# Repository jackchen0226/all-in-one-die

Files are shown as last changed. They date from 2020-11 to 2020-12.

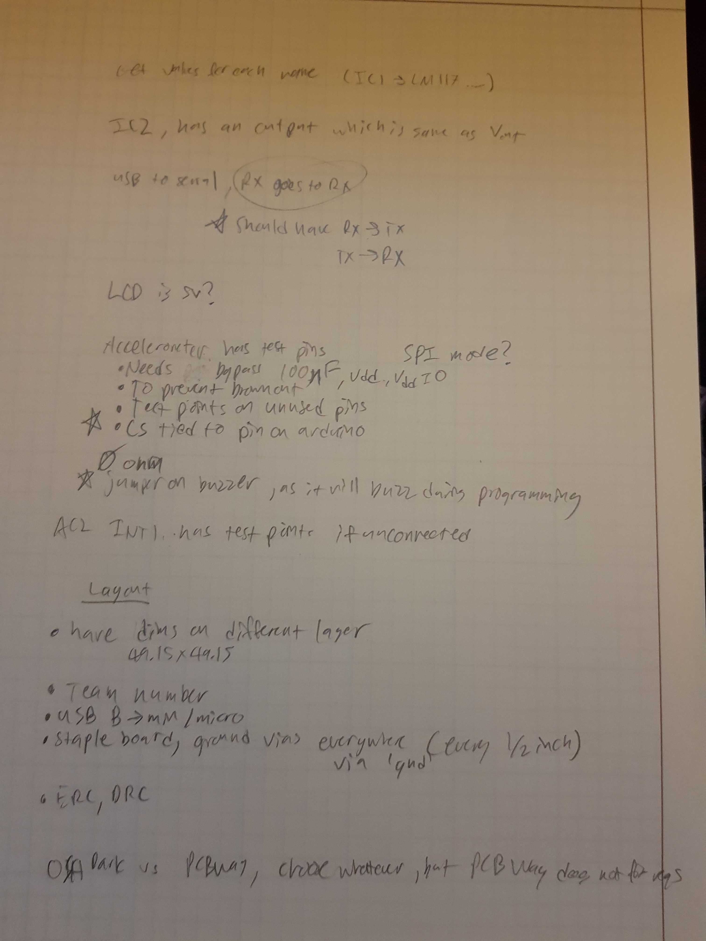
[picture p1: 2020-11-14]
docs/Design Reviews/2020-11-14/20201114_132937.jpg

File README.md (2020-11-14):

<p align="center">
  Team 7
</p>

<h3 align="center">ECE 411 Practicum Project</h3>

<p align="center">
  Practicum Project for Team 3 (Fall 2020)
  <br>
  <a href="https://github.com/jackchen0226/all-in-one-die/wiki"><strong>Team Wiki »</strong></a>
  <br>
  <br>
</p>

## Table of contents

- [Status](#status)
- [Overview](#overview)
- [Documentation](#documentation)
- [Creators](#creators)

## Status

All aspects are currently being developed, reviewed, and tested.

## Overview

All-in-One-Die is an extra-large die that you can shake with your own two hands! Large enough to be larger than your average d6 or d20, and it ‘rolls’ when you shake it. Additionally, when a 1 is rolled, an extremely negative sound will be played. This is for those who enjoy tabletop gaming and want a fun novelty item that is interactive.

Not family-friendly may involve swearing

## Documentation

Will be included upon completion.

## Creators

Hannah Mortimer (hmort2@pdx.edu) <br />
Devon Mickels (dmickels@pdx.edu) <br />
Nicole Fellows  (nicol27@pdx.edu) <br />
Jack Chen (chenjac@pdx.edu)

## 3 Brainstormed Ideas:

All-in-one-die  <br />
Farmbot <br />
Replacement Piano Key <br />

Please look at the [project ideas](https://github.com/jackchen0226/all-in-one-die/wiki/Project-Ideas) for full descriptions of all 3 ideas!

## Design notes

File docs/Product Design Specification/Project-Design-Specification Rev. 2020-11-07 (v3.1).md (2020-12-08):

Current Revision: 2020-11-07 (v3.1)

## Executive Summary / Concept of Operations

All-in-One-Die is an extra-large die that you can shake with your own two hands! Large enough to be bigger than your average d6 or d20, and it ‘rolls’ when you shake it. When a 1 is rolled, an extremely negative sound* will be played. Perfect for those who enjoy tabletop gaming and want a fun interactive novelty item. 

\*Not family friendly, may involve swearing

## Brief Market Analysis

The need for varying value dice is frequently felt by the tabletop gaming community. Games such as _Dungeons and Dragons_ and _Magic the Gathering_ require the use of dice for tracking the number of creatures a player can create, damage caused, and other game effects. In an average game of this type, a player can expect to have at least one set of gaming dice. A typical set will have 1 of each of the following: d4, d6, d8, d10, d12, d20, with each value ‘n’ after ‘d’ representing the possible rolls from 1 to n. Instead of having to carry around a bunch of dice, the All-in-One-Die will provide the customer with a handheld device capable of rolling each type of die.

Looking at what is available in the market for tabletop gaming, no handheld devices that match this design's functionality currently exist. There are some simple boards capable of displaying a roll on LEDs but those don’t have a practical application for gaming. The biggest competition comes from dice rolling apps and websites. While these offer a quick solution to being able to roll dice of different values, it lacks the hands on feel many gamers enjoy. Arguably, there are digital versions of games, but the type of customers this device is for want something they can physically play with. A big selling point of the device is the novelty of it and having a tangible accessory to improve the gaming experience.

Going over early projections of the cost of production, it would cost about $232.00 to manufacture 100 boards, equating to about $2.00 a board, added components and batteries brings the total up to about $20.00 per board. Using this production cost, and considering the limited batch being made, the device would be sold for about $40.00-$50.00. This cost could be brought down if it were being mass produced.

## Requirements
This project MUST:
* Have some input to change the size of the die
* Be fully enclosed in a case with the exception of inputs
* Have an on/off switch
* Have an audio device to play a sound effect upon rolling a 1
* Have a way to detect shaking of the die
* Have a screen that displays the result of the roll.
* Be portable and battery-powered with replaceable batteries
* Battery power lasts at least 1 hour
* Contain a processor
* Be live documented on Github Wiki

This project SHOULD:
* Have rechargeable batteries 
* Be created on a PCB that is as small as possible
* Contain mostly hand solder surface mount components on the board
* Have documentation and issues tracked on Github

## System Architecture
### High-Level Diagram

High level diagram, because block diagrams are important

### Low-level diagram

Low level diagram, just y'know ignore the low resolution.

## Design Specification
* Processor: ATMega328P
* Actuator: LCD Screen and Speaker
* Sensor: Accelerometer (LIS3L02AQ3)
* USB to Serial: FT232RL
* Power: 3.3V-5V
* Using Arduino IDE

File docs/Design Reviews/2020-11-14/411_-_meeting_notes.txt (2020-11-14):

team 3 

overview:
project is for tabletop gaming and the device is houses a screen and a dial on side to select
the type of die you want to roll so you can go 4 8 12 20, shake it, and it displays and and you have option to roll again or select diff

block diagram:
sensor: - lis3dh accelorometer set right now to high sensitivity, someone could set off false rolls, and a potentiometer for the button
	we didn't want to use buttons on the device, all functionality is broken into the potentiometer and the timing
Andy: i like that - thought to the UX

actuator: - with the sensor reading botht the shake and pot setting, it displays onto an oled screen - 128*32 screen, you can include messages (andy asked about messages) andrew - put skull and cross bones on it, hahahah
oled is output - other output is the buzzer for a nat 1, sound,
the controller atmega32
power supply - batteries - 4 AAs (6 volts into 5 volts)

Mini Design Review:
Devon sharing screen: the schematic overview - 
looking at power first - 2 parts, the dc female to take in power with 5v regulator, power led to show that we are getting proper power, added 3.3v for the accelormeter to conver down
	and: good job on the 5v - burn less power
		few things: what is ic1 - no value associated with it - voltage regulator we pulled off of mouser 7805? use value command so it's not just a black box - no black boxes
				lm1117 - it's got a vout, input, adj/gnd and output - the datasheet uses 4 pins but table only shows the 3 pins, 3.3v output - the tab on the transistor - vout
			we will plug batteries into that - putting the diode in there is good
			usb to serial: it's adorable - stick with low power module, miniusb port, good job on shield for capacitor to gnd, rx goes to rx - yup that's wrong, on a UART rx goes to tx, and tx goes to rx, know it and connect appropraitely
			crystal resonator is fine - good job on the bypass caps
			icsp - we gett to program it, arduino ecosystem, reset goes to left to reset the dtr thing - the lcd goes to some pins and that's 5v as well, the lcd 5v in/out? not super verified, but we have been using 5v
			Accelerometer: have a jumper that is being used as test point, incase we need to use an external, this could be a pain cause small
			WE NEED BYPASS CAPS 100nF whereever there is vdd (at least 2), any single chip that is off in space need local charge resovoirs
			using spie mode- great
			not sure we want to ground chip-select, in spie mode it needs to go to output for the chip select, cs tied to pin on arduino - we need taht, spie requires cs to go from high to low to start process
			strongly suggest test points on unused pins on microcontrollera nd accelerometer
			driving buzzer directly which is probably okay - we proabbly need to have a jumper in our buzzer so we can disconnect it when we are programming it - 0 ohm resistor or something so we can program without the buzzer in place
			run erc - interuupt pins can go to test points - or not, up to us - and then we have std power warnings that we can approve
			excellent - good schematic

		layout: all fired
			gnd plane on both sides - good
			change dimensions to different layer - they are currently copper 
			power is thick - nice
			team number needed ece411-tx-xxx (follow instructions completely)
			current goal is make board
			where is usb connector? - we have type b connector oop - it'll work, just giant
			really really good
			clean up team name layer 
			dis -tval
			more to clean up but fine
			last thing need to do - staple your board, add gnd vias every 1/2 in or so, us via cmd, via 'gnd' - put those everywhere so ground works well - in places where gnd signal cut in pieces - more the merrier
			drc - air wires and stuff to fix, make sure all are clear and we are good.

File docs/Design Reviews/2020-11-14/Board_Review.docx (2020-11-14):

Board Review with Andrew Greenberg

Power:

- Liked the linear regulator, will burn less power.
- What is IC1 running to on the power supply? Use a value set pin.
- Don’t connect Vout on the 3.3V linear regulator

USB -> Serial:

- Caps to ground look good.
- RX shouldn’t connect to RX, TX shouldn’t connect to TX, know which is input/output.

OLED:

- Double check voltage being used for screen.

Buzzer:

- Put 0 ohm resistor on buzzer so it doesn’t mess up programming.

Accelerometer:

- Can use pin 10,10 as test points

Board:

- Change dimensions to different layer, it’s currently only on one and OSH park won’t like it
- Clean up team name on board.
- USB is kind of large
- Staple board
  - Ground vias every ½ inch, the more the better
- Board dimension is actual 4 square inches

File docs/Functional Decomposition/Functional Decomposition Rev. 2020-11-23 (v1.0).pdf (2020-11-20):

System Design: Functional Decomposition

Team 03 – Jack Chen, Devon Mickels, Hannah Mortimer, Nicole Fellows

High Level Block Diagram

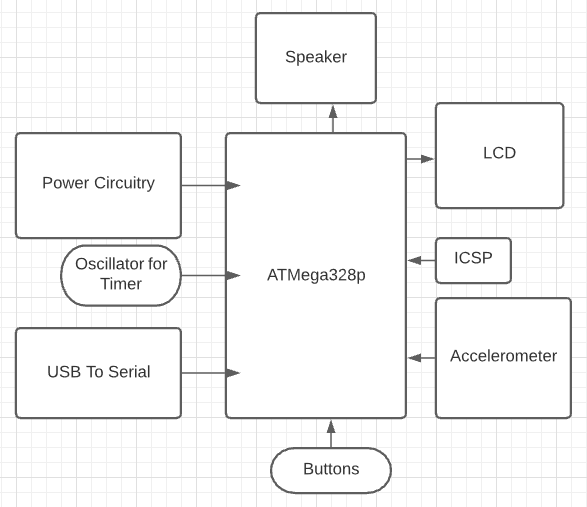
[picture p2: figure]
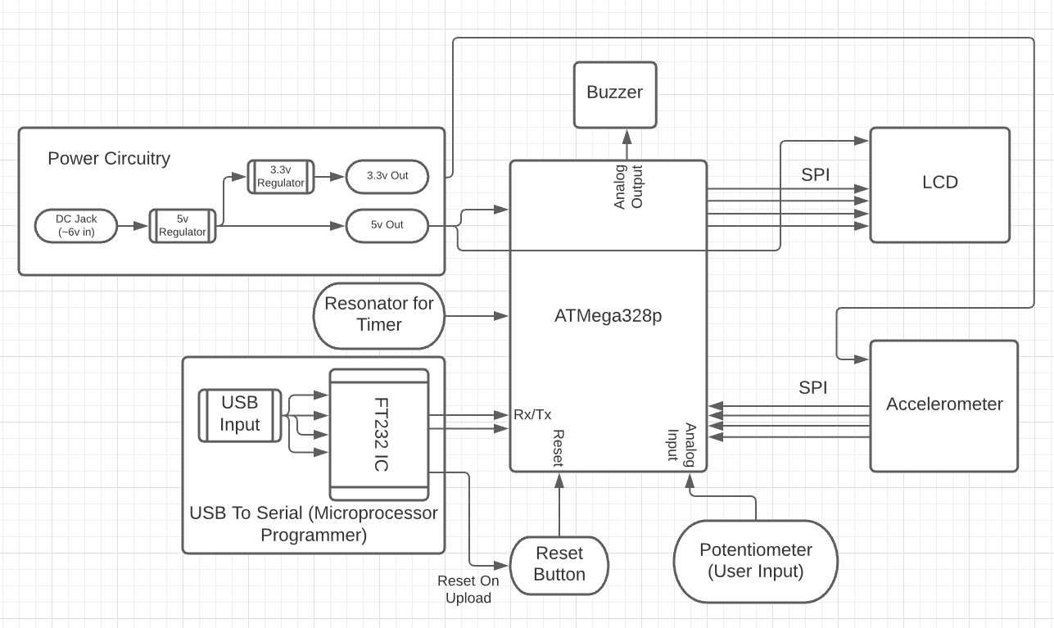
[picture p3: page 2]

Low Level Block Diagram

Power Circuitry

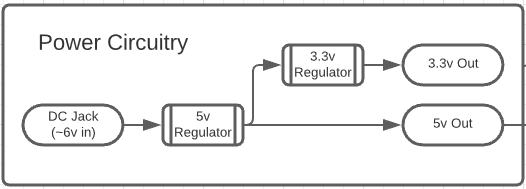
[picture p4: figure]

Module | Power Circuitry
Inputs | 6V
Outputs | 5V and 3.3V
Functionality | Converts 6v power from battery pack into a 5v and 3.3v line to power different components in the system.

USB To Serial

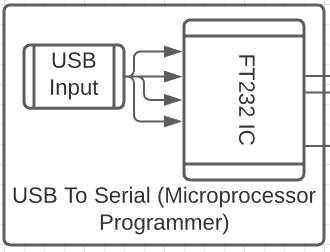
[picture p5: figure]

Module | Power Circuitry
Inputs | USB B Cable
Outputs | TX, RX and DTR signal.
Functionality | Used to convert an incoming USB signal to a usable serial communication protocol for use in programming the ATMEGA328p

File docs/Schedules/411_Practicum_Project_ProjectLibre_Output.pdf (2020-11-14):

1 | First Team Meeting | 1 day | 9/28/20 8:00 AM | 9/28/20 5:00 PM
2 | Define Requirements | 1 day | 9/28/20 8:00 AM | 9/28/20 5:00 PM
3 | Create Project Idea | 4 days | 9/29/20 8:00 AM | 10/2/20 5:00 PM | 2
4 | Verify Project Meets Requirements | 0 days | 9/28/20 8:00 AM | 9/28/20 8:00 AM
5 | Create Collaboration Site | 3 days | 9/28/20 8:00 AM | 9/30/20 5:00 PM | 4
6 | Write PDS | 2 days | 9/28/20 8:00 AM | 9/29/20 5:00 PM | 4
7 | Review PDS | 0 days | 9/29/20 5:00 PM | 9/29/20 5:00 PM | 6
8 | Define High Level Description of Device | 1 day | 9/28/20 8:00 AM | 9/28/20 5:00 PM | 4
9 | Review Design | 0 days | 9/28/20 5:00 PM | 9/28/20 5:00 PM | 8
10 | Research Parts | 4 days | 9/29/20 8:00 AM | 10/2/20 5:00 PM | 9
11 | Research Accelerometers | 1 day | 9/29/20 8:00 AM | 9/29/20 5:00 PM
12 | Research Processors | 1 day | 9/29/20 8:00 AM | 9/29/20 5:00 PM
13 | Research Displays | 1 day | 9/29/20 8:00 AM | 9/29/20 5:00 PM
14 | Determine Power Source | 1 day | 9/29/20 8:00 AM | 9/29/20 5:00 PM
15 | Research Necessary Connections | 3 days | 9/29/20 8:00 AM | 10/1/20 5:00 PM
16 | Research PCB Manufacturers | 1 day | 9/29/20 8:00 AM | 9/29/20 5:00 PM
17 | Create Rough Draft of BOM | 1 day | 10/2/20 8:00 AM | 10/2/20 5:00 PM | 11;12;13;15
18 | Review Draft of BOM | 0 days | 10/2/20 5:00 PM | 10/2/20 5:00 PM | 17
19 | Design PCB | 28 days | 10/5/20 8:00 AM | 11/11/20 4:59 PM | 9;18
20 | Download EagleCAD | 1 day | 10/5/20 8:00 AM | 10/5/20 5:00 PM
21 | Review Working with EagleCAD | 1 day | 10/5/20 8:00 AM | 10/5/20 5:00 PM
22 | Research Board Layout for Processor | 5 days | 10/5/20 8:00 AM | 10/9/20 4:59 PM
23 | Create Preliminary Block Diagram | 5 days | 10/9/20 4:59 PM | 10/16/20 4:59 PM | 18;22
24 | Revise Block Diagram | 5 days | 10/9/20 4:59 PM | 10/16/20 4:59 PM
25 | Review Block Diagram | 0 days | 10/9/20 4:59 PM | 10/9/20 4:59 PM
26 | Design Traces | 9 days | 10/9/20 4:59 PM | 10/22/20 4:59 PM | 25
27 | Determine Pins Needed | 1 day | 10/9/20 4:59 PM | 10/12/20 4:59 PM | 25
28 | Create Schematic | 4 days | 10/12/20 4:59 PM | 10/16/20 4:59 PM | 27
29 | Review Schematic | 0 days | 10/16/20 4:59 PM | 10/16/20 4:59 PM | 28
30 | Final Revise of Schematic | 4 days | 10/16/20 4:59 PM | 10/22/20 4:59 PM | 29
31 | Accept Schematic | 0 days | 10/22/20 4:59 PM | 10/22/20 4:59 PM | 30
32 | Build Breadboard Prototypes | 14 days | 10/22/20 4:59 PM | 11/11/20 4:59 PM | 31
33 | Order Parts | 13 days | 10/22/20 4:59 PM | 11/10/20 4:59 PM
34 | Order Parts According to BOM | 1 day | 10/22/20 4:59 PM | 10/23/20 4:59 PM | 31
35 | Wait for Delays in Shipping | 7 days | 10/23/20 4:59 PM | 11/3/20 4:59 PM | 34
Name | Duration | Start | Finish | Predecessors

411 Practicum Project - page1

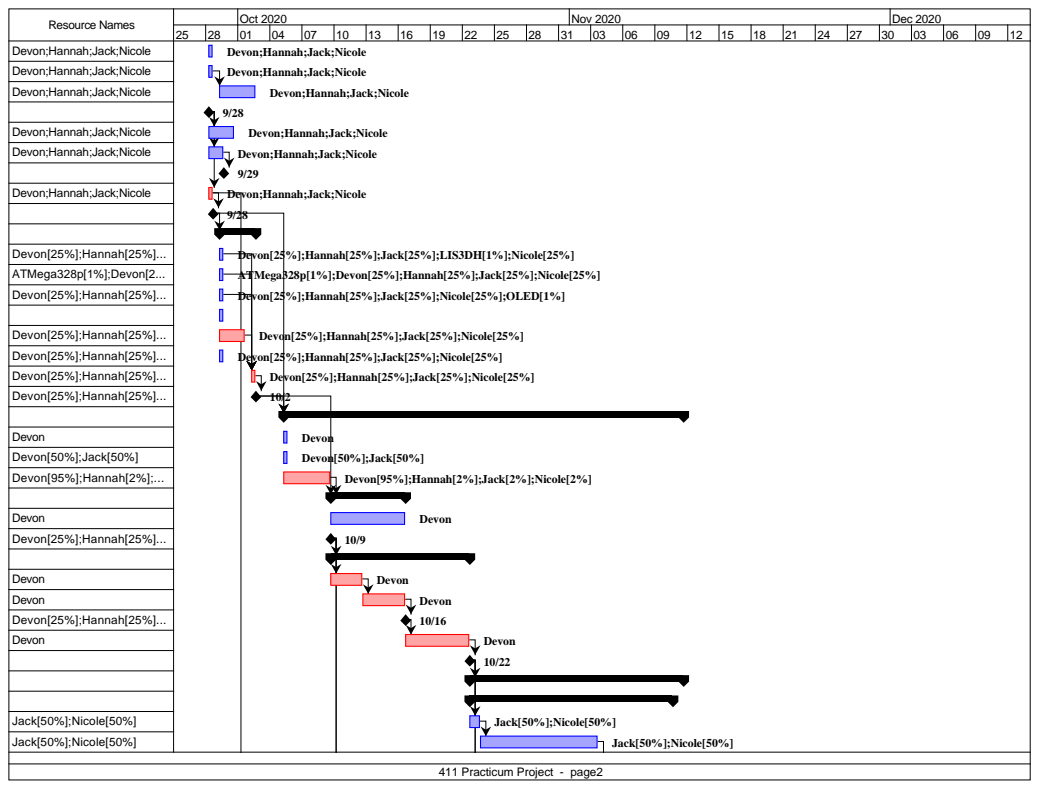
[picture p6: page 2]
Oct 2020; Nov 2020; Dec 2020; Devon[25%];Hannah[25%]... ATMega328p[1%];Devon[2... Devon[25%];Hannah[25%]...; Devon[25%];Hannah[25%]... Devon[25%];Hannah[25%]... Devon[25%];Hannah[25%]... Devon[25%];Hannah[25%]...; Devon Devon[50%];Jack[50%] Devon[95%];Hannah[2%];...; Devon Devon[25%];Hannah[25%]...; Devon Devon Devon[25%];Hannah[25%]... Devon; Jack[50%];Nicole[50%] Jack[50%];Nicole[50%]; Devon; Devon[50%];Jack[50%]; Jack[50%];Nicole[50%]

Resource Names
Devon;Hannah;Jack;Nicole

Devon[25%];Hannah[25%];Jack[25%];LIS3DH[1%];Nicole[25%]
ATMega328p[1%];Devon[25%];Hannah[25%];Jack[25%];Nicole[25%]
Devon[25%];Hannah[25%];Jack[25%];Nicole[25%];OLED[1%]

Devon[25%];Hannah[25%];Jack[25%];Nicole[25%]

Devon[95%];Hannah[2%];Jack[2%];Nicole[2%]

06 | 09 | 12 | 15 | 18 | 21 | 24 | 27 | 30 | 02 Jan 2021
05 | 08 | 11 | 14 | 17 | 20 | 23

36 | Preliminary Build of Boards | 11 days | 10/22/20 4:59 PM | 11/6/20 4:59 PM
37 | Build First Prototype | 3 days | 10/22/20 4:59 PM | 10/27/20 4:59 PM | 31
38 | Build Second Prototype | 3 days | 11/3/20 4:59 PM | 11/6/20 4:59 PM | 35
39 | Review Parts | 0 days | 11/6/20 4:59 PM | 11/6/20 4:59 PM | 37;38
40 | Order Secondary Parts | 2 days | 11/6/20 4:59 PM | 11/10/20 4:59 PM | 39
41 | Update Prototypes with Secondary P... | 1 day | 11/10/20 4:59 PM | 11/11/20 4:59 PM | 40
42 | Write Code | 40 days | 10/1/20 8:00 AM | 11/25/20 5:00 PM
43 | Create High Level Description of Code | 1 day | 10/1/20 8:00 AM | 10/1/20 5:00 PM | 8
44 | Define Modular Sections | 24 days | 10/2/20 8:00 AM | 11/4/20 4:59 PM | 43
45 | Read Potentiometer Setting | 1 day | 10/2/20 8:00 AM | 10/2/20 5:00 PM | 43
46 | Determine Die Number | 1 day | 10/5/20 8:00 AM | 10/5/20 5:00 PM | 45
47 | Sense Shake | 3 days | 10/6/20 8:00 AM | 10/8/20 5:00 PM | 46
48 | Rolling Again | 2 days | 10/9/20 8:00 AM | 10/12/20 5:00 PM | 47
49 | Set Response for 1 Being Rolled | 3 days | 10/13/20 8:00 AM | 10/15/20 5:00 PM | 48
50 | Display Prompts and Results on Display | 2 days | 10/16/20 8:00 AM | 10/19/20 5:00 PM | 49
51 | Compile Code | 0 days | 10/19/20 5:00 PM | 10/19/20 5:00 PM | 50
52 | Breadboard Testing | 6 days | 10/27/20 4:59 PM | 11/4/20 4:59 PM | 37
53 | Upload Code | 0 days | 10/27/20 4:59 PM | 10/27/20 4:59 PM | 51
54 | Check Each Modular Section | 5 days | 10/27/20 4:59 PM | 11/3/20 4:59 PM | 51
55 | Check Sensor Values | 1 day | 10/27/20 4:59 PM | 10/28/20 4:59 PM | 51
56 | Check Accelerometer Sensitivity | 1 day | 10/28/20 4:59 PM | 10/29/20 4:59 PM | 55
57 | Check Rolls are Corrent and Ran... | 1 day | 10/29/20 4:59 PM | 10/30/20 4:59 PM | 56
58 | Check Buzzer Response for 1 | 1 day | 10/30/20 4:59 PM | 11/2/20 4:59 PM | 57
59 | Check Display Shows Prompts an... | 1 day | 11/2/20 4:59 PM | 11/3/20 4:59 PM | 58
60 | Final Breadboard Prototype Check | 1 day | 11/3/20 4:59 PM | 11/4/20 4:59 PM | 55;56;57;58;59
61 | Accept Final Prototypes | 0 days | 11/4/20 4:59 PM | 11/4/20 4:59 PM | 60
62 | Final Code Review | 4 days | 11/4/20 4:59 PM | 11/10/20 4:59 PM | 61
63 | Review Code | 0 days | 11/4/20 4:59 PM | 11/4/20 4:59 PM | 61
64 | Test Complete Code | 3 days | 11/4/20 4:59 PM | 11/9/20 4:59 PM | 63
65 | Revise Code | 1 day | 11/9/20 4:59 PM | 11/10/20 4:59 PM | 64
66 | Code Accepted | 0 days | 11/10/20 4:59 PM | 11/10/20 4:59 PM | 65
67 | Board Review | 11 days | 11/10/20 4:59 PM | 11/25/20 5:00 PM | 60;65
68 | Update Design from Prototype/Code ... | 1 day | 11/10/20 4:59 PM | 11/11/20 4:59 PM | 60;65
69 | Set Up Meeting with Other Team | 1 day | 11/11/20 4:59 PM | 11/12/20 4:59 PM | 68
70 | Share Board with Andrew Greenberg | 1 day | 11/11/20 4:59 PM | 11/12/20 4:59 PM | 68
Name | Duration | Start | Finish | Predecessors

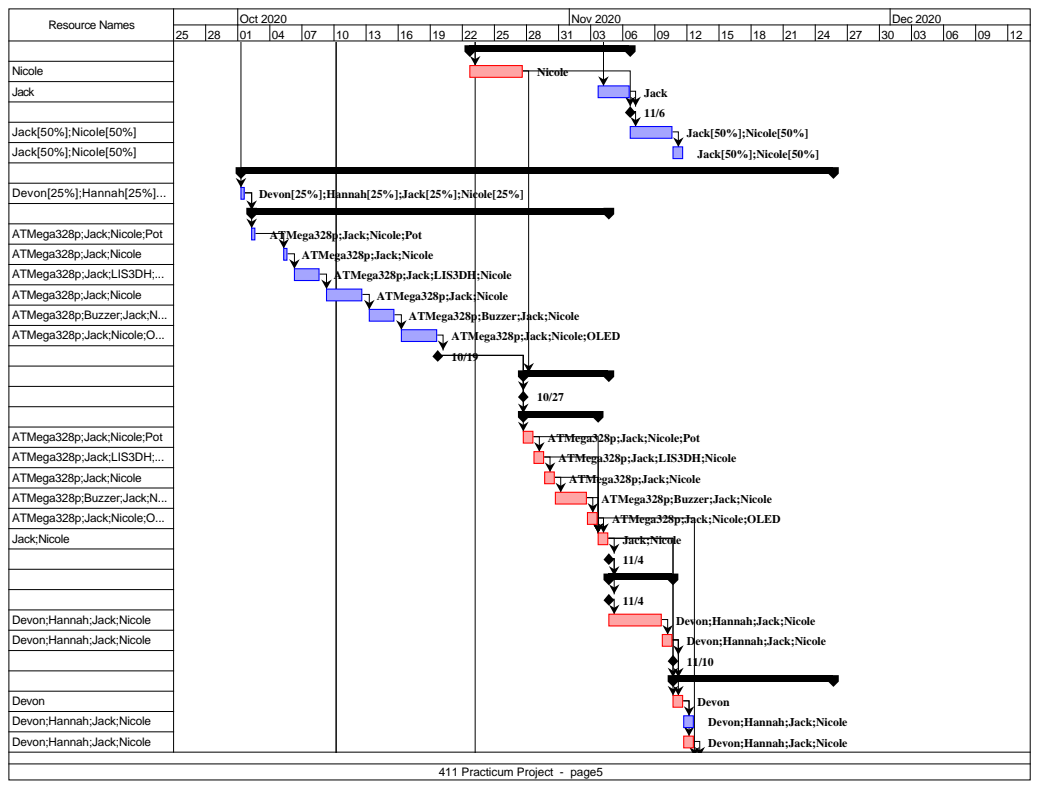
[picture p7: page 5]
Oct 2020; Nov 2020; Dec 2020; Nicole Jack; Jack[50%];Nicole[50%] Jack[50%];Nicole[50%]; Devon[25%];Hannah[25%]...; Resource Names; Nicole; Jack; Jack[50%];Nicole[50%]

Devon[25%];Hannah[25%];Jack[25%];Nicole[25%]

ATMega328p;Jack;Nicole;Pot
ATMega328p;Jack;Nicole
ATMega328p;Jack;LIS3DH;...
ATMega328p;Buzzer;Jack;N...
ATMega328p;Jack;Nicole;O...

ATMega328p;Jack;LIS3DH;Nicole

ATMega328p;Buzzer;Jack;Nicole

ATMega328p;Jack;Nicole;OLED

Jack;Nicole

Devon;Hannah;Jack;Nicole

Devon

06 | 09 | 12 | 15 | 18 | 21 | 24 | 27 | 30 | 02 Jan 2021
05 | 08 | 11 | 14 | 17 | 20 | 23

71 | Revise Board | 1 day | 11/12/20 4:59 PM | 11/13/20 4:59 PM | 59;70
72 | Design PCB Panelization | 1 day | 11/13/20 4:59 PM | 11/16/20 4:59 PM | 71
73 | Review Final Layout | 0 days | 11/16/20 4:59 PM | 11/16/20 4:59 PM | 72
74 | Compile Final BOM | 1 day | 11/16/20 4:59 PM | 11/17/20 4:59 PM | 73
75 | Order PCB | 6 days | 11/17/20 4:59 PM | 11/25/20 5:00 PM | 74
76 | Design 3D Printed Housing | 34 days | 10/9/20 4:59 PM | 11/26/20 4:59 PM | 25
77 | Sketch Initial Designs | 4 days | 10/9/20 4:59 PM | 10/15/20 4:59 PM | 25
78 | Define Case Dimensions | 4 days | 10/22/20 4:59 PM | 10/28/20 4:59 PM | 31;77
79 | Review Case Design | 1 day | 10/28/20 4:59 PM | 10/29/20 4:59 PM | 78
80 | 3D Model Sketch | 5 days | 10/29/20 4:59 PM | 11/5/20 4:59 PM | 79
81 | Revise Case Based on Previous Design ... | 4 days | 11/13/20 4:59 PM | 11/19/20 4:59 PM | 71;80
82 | Optimize Sketch for Modular Construction | 3 days | 11/19/20 4:59 PM | 11/24/20 4:59 PM | 81
83 | Final Review of Case Design | 0 days | 11/24/20 4:59 PM | 11/24/20 4:59 PM | 82
84 | Print Housing | 2 days | 11/24/20 4:59 PM | 11/26/20 4:59 PM | 83
85 | Final Construction | 7 days | 11/26/20 8:00 AM | 12/4/20 5:00 PM | 75
86 | Test Board | 1 day | 11/26/20 8:00 AM | 11/26/20 5:00 PM | 75
87 | Revise Traces and Components | 1 day | 11/27/20 8:00 AM | 11/27/20 5:00 PM | 86
88 | House Device | 2 days | 11/30/20 8:00 AM | 12/1/20 5:00 PM | 87
89 | Test Device in Case | 1 day | 12/2/20 8:00 AM | 12/2/20 5:00 PM | 88
90 | Final Check | 1 day | 12/3/20 8:00 AM | 12/3/20 5:00 PM | 89
91 | Final Revision | 1 day | 12/4/20 8:00 AM | 12/4/20 5:00 PM | 90
92 | Accept Final Device | 0 days | 12/4/20 5:00 PM | 12/4/20 5:00 PM | 91
93 | CELEBRATE PROJECT COMPLETE!! | 0 days | 12/4/20 5:00 PM | 12/4/20 5:00 PM | 92
Name | Duration | Start | Finish | Predecessors

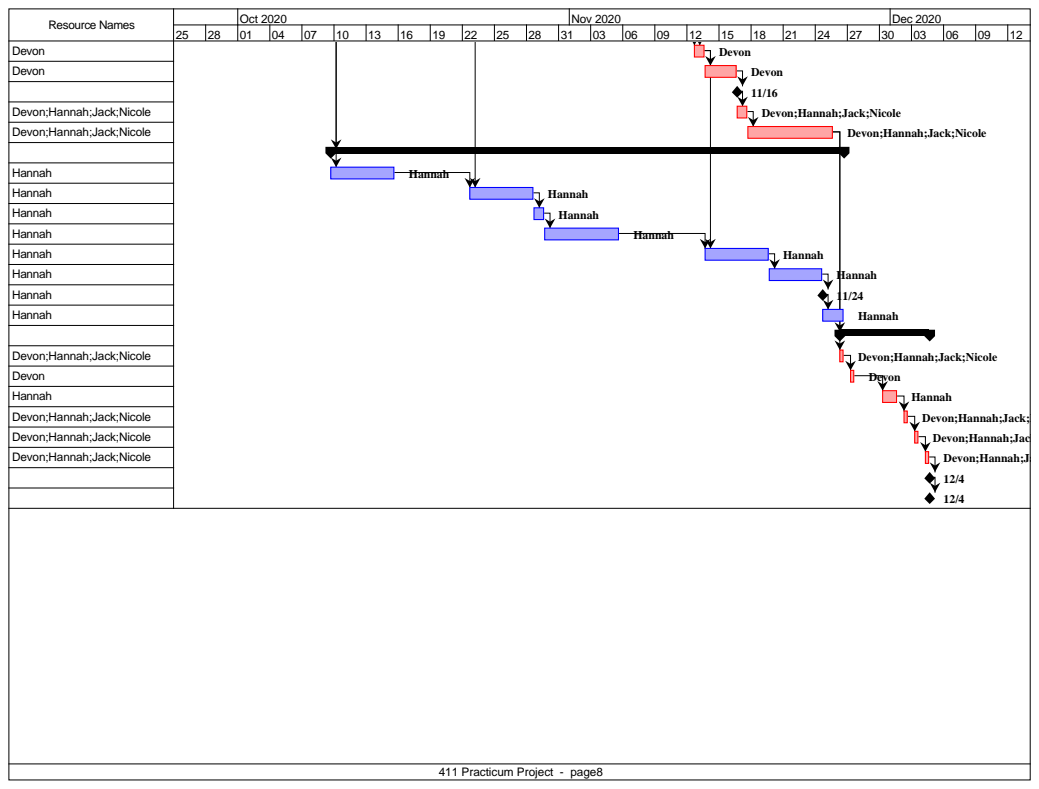
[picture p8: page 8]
Oct 2020; Nov 2020; Dec 2020; Devon Devon; Hannah Hannah Hannah Hannah Hannah Hannah Hannah Hannah; Resource Names; Hannah

Devon
Devon;Hannah;Jack;Nicole

Hannah

06 | 09 | 12 | 15 | 18 | 21 | 24 | 27 | 30 | 02 Jan 2021
05 | 08 | 11 | 14 | 17 | 20 | 23

Devon;Hannah;Jack;Nicole

Devon;Hannah;Jack;Nicole
Devon;Hannah;Jack;Nicole
Devon;Hannah;Jack;Nicole

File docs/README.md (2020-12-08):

While organized, some files may be out of date or missing. Check the wiki for updated versions.

https://github.com/jackchen0226/all-in-one-die/wiki

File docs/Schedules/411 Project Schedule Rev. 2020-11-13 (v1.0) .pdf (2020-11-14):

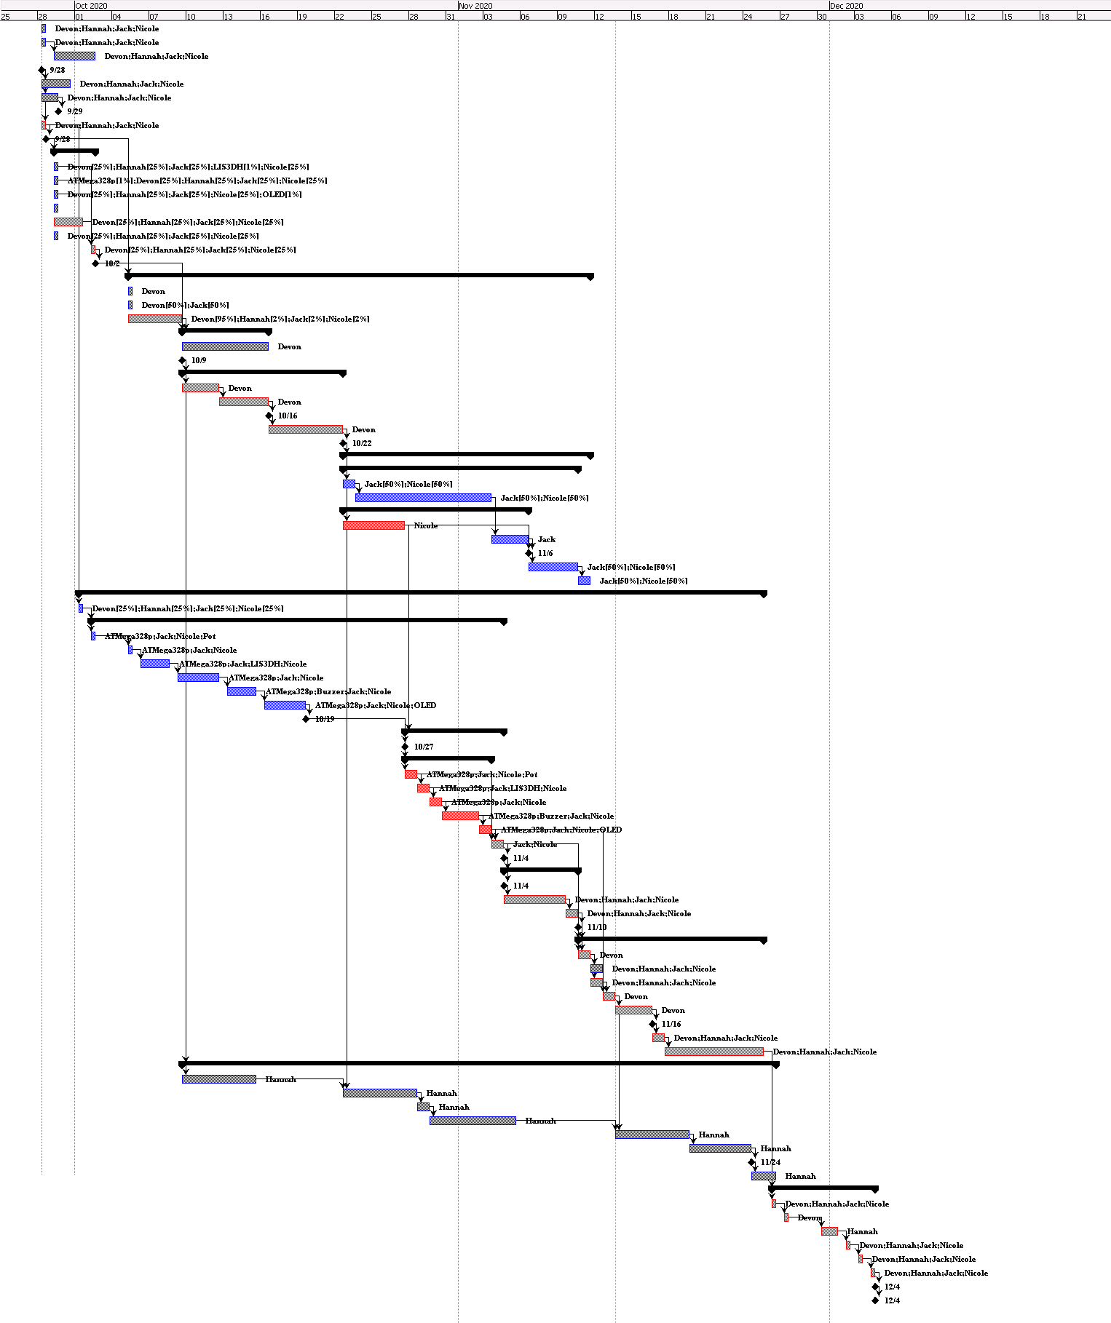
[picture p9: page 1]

The image above is the Gannt chart for Team 3. The assigned resources appear next to each task.

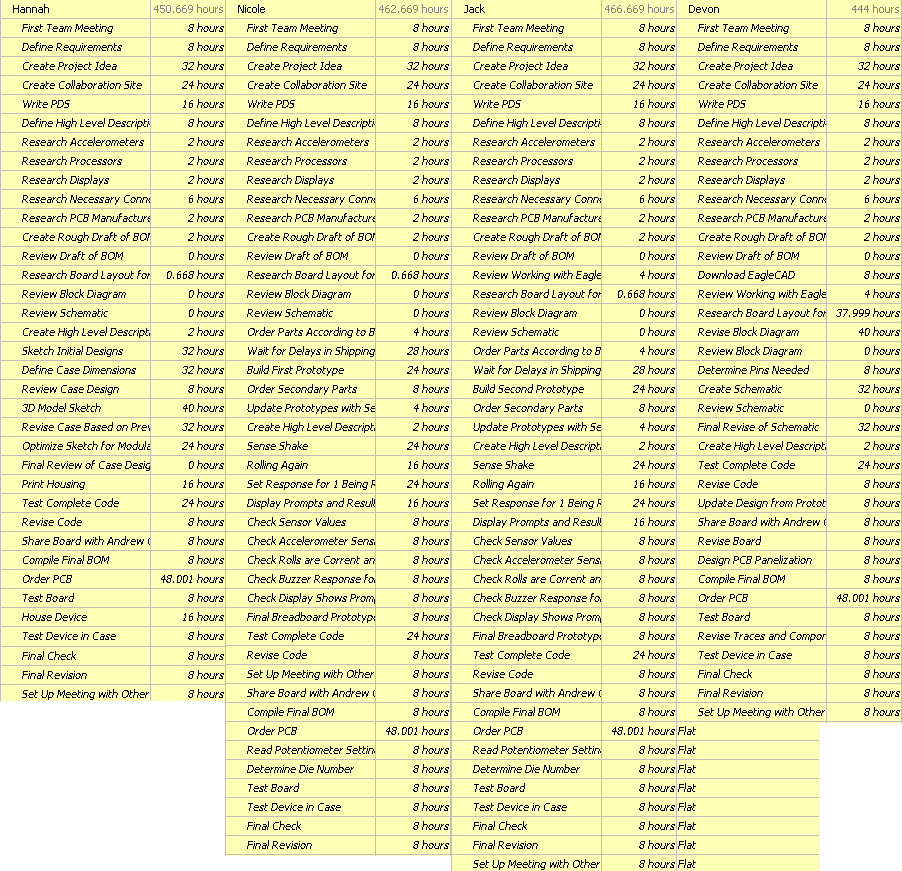
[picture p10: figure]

The image above displays the load balancing for each team member. The hours of work are fairly evenly divided amongst each team member.

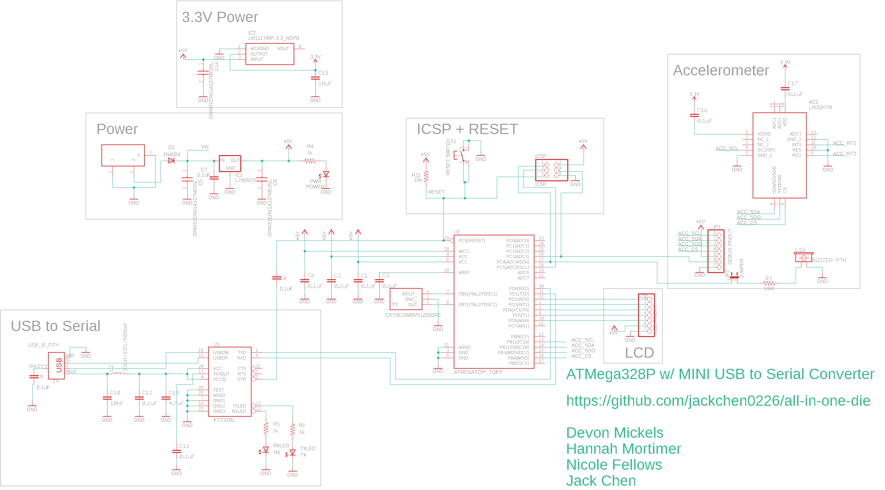
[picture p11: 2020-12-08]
brd/Schematic V6.png

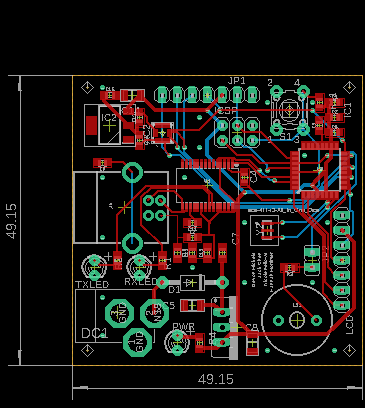
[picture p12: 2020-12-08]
brd/Layout V6.png

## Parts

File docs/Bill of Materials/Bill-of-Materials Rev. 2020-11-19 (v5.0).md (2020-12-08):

# PCB Bill of Materials

Table of the Bill of Materials used in the PCB... because making tables in Markdown is hard

https://github.com/jackchen0226/all-in-one-die/tree/main/docs/Bill%20of%20Materials

## Links to various components
### Passive components
* Cap 0.1uF <https://www.mouser.com/ProductDetail/KEMET/C0603X104K5RAC3316?qs=PzGy0jfpSMver6vEANBjUA%3D%3D>
* (C10) 0.01uF  <https://www.mouser.com/ProductDetail/KEMET/C0603C103K5RAC7013?qs=rxL5I1UrDR%2FDLdVRYcoJRw%3D%3D>
* (C13) 4.7uF <https://www.mouser.com/ProductDetail/Taiyo-Yuden/LMK107BJ475MAHT?qs=vF%252B8ahGVile95bhfG0202g%3D%3D>
* **(C5, C8) 100uF THRU-HOLE OUT OF STOCK** <https://www.mouser.com/ProductDetail/KEMET/A750BK107M1AAAE024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>
* (C16, C17) 30pF <https://www.mouser.com/ProductDetail/KEMET/C0603C300M5HACAUTO?qs=j%252B1pi9TdxUaaw3mykHTYsA%3D%3D>
* (R11) 10k Resistor <https://www.mouser.com/ProductDetail/Panasonic/ERJ-UP3D1002V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>
* Resistor 1K <https://www.mouser.com/ProductDetail/Vishay-Dale/RCC06031K00FKEA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>
* Power LED (the TX, RX LED end with 4500 instead of 4100) <https://www.mouser.com/ProductDetail/VCC/LTH3MM12VFR4100?qs=Mv7BduZupUhznjtoVCBbVQ%3D%3D>
* (L2) 33mH <https://www.mouser.com/ProductDetail/Murata-Electronics/LQW18AS33NJ0CD?qs=B6kkDfuK7%2FBxhLXLrxlYwQ%3D%3D>
* (C15) 10uF <https://www.mouser.com/ProductDetail/TDK/CGA3E1X7T0G106M080AC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>
* (R3) 100 Resistor <https://www.mouser.com/ProductDetail/Vishay-Dale/RCC0603100RFKEA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>

### ICs and single use components
* USB to serial chip <https://www.mouser.com/ProductDetail/FTDI/FT232RL-REEL?qs=D1%2FPMqvA103RC6OU6bKtoA%3D%3D>
* USB B Connector <https://www.mouser.com/ProductDetail/Amphenol-FCI/61729-0010BLF?qs=Lu3apKW7jUhgLQlMxtWsEQ%3D%3D>
* DC power jack <https://www.mouser.com/ProductDetail/Gravitech/CON-SOCJ-2155?qs=fkzBJ5HM%252BdCcpvFQyQZHtA%3D%3D>
* ATMega328p <https://www.mouser.com/ProductDetail/Microchip-Technology-Atmel/ATMEGA328P-AU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>
* Buzzer <https://www.mouser.com/ProductDetail/TDK/SD1209T5-A1?qs=6QK9sRmt5TllZYgulSSkFw%3D%3D>
* Switch <https://www.mouser.com/ProductDetail/Omron-Electronics/B3F-1000?qs=lK7M36XCk6JQHckSc1xIsg%3D%3D>
* Diode <https://www.mouser.com/ProductDetail/Diodes-Incorporated/1N4004-T?qs=e%2FRqmsgwm9h5YfUmULbvEw%3D%3D>
* Accelerometer <https://www.mouser.com/ProductDetail/STMicroelectronics/LIS3DHTR?qs=6la6oa3D8xzhXYax3cEo4w%3D%3D>
* 7-pin headers <https://www.mouser.com/ProductDetail/Harwin/M20-9770746?qs=Jph8NoUxIfW4IDi91nhySw%3D%3D>
* (ICSP) 2x3-pin header <https://www.mouser.com/ProductDetail/Harwin/M20-9980346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>
* 2-pin jumper header <https://www.mouser.com/ProductDetail/Harwin/M20-9990246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>
* 16-MHz crystal <https://www.mouser.com/ProductDetail/Murata-Electronics/CSTNE16M0V51Z000R0?qs=xZ%2FP%252Ba9zWqYJTgLasPOhOA==>

# Bill of Materials for Breadboard Prototype (WIP):

## Breadboard Prototyping:
- [ ] ATMega328P [[Amazon](https://www.amazon.com/Fii-X3-Atmega328P-PU-Bundle-Sockets/dp/B018ZR3F7O/), [Microchip](https://www.microchip.com/wwwproducts/en/ATmega328p)]
- [ ] Accelerometer [[Adafruit](https://www.adafruit.com/product/2809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)]
- [ ] LCD Screen [[Amazon](https://www.amazon.com/UCTRONICS-SSD1306-Self-Luminous-Display-Raspberry/dp/B072Q2X2LL)]
- [ ] Mini USB to Serial Converter [[Amazon](https://www.amazon.com/HiLetgo-FT232RL-Converter-Adapter-Breakout/dp/B00IJXZQ7C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)]

## Final Construction:
- [ ] Assembled PCB
- [ ] LCD Screen [[Amazon](https://www.amazon.com/UCTRONICS-SSD1306-Self-Luminous-Display-Raspberry/dp/B072Q2X2LL)]
- [ ] 4xAA Battery Holder [[Amazon-Flat](https://www.amazon.com/LAMPVPATH-Battery-Holder-Leads-Wires/dp/B07T7MTRZX/), [Amazon-Fat](https://www.amazon.com/LAMPVPATH-Battery-Connector-Plastic-Housing/dp/B01MAXT00Q/)]

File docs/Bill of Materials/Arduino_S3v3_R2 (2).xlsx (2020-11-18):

Item # | Designator | Qty | Manufacturer | Mfg Part # | Description | Package
1 | C1, C2, C3, C4, C6, C7, C9, C11, C12, C16, C17 | 11 | KEMET | C0603X104K5RAC3316 | 0.1µF ceramic capacitors | 0603
2 | R3 | 1 | Vishay / Dale | RCC0603100RFKEA | 100Ω resistor | 0603
3 | R11 | 1 | Panasonic | ERJ-UP3D1002V | 10kΩ resistor | 0603
4 | C10 | 1 | KEMET | C0603C103K5RAC7013 | 0.01uF/10nF/10,000pF ceramic capacitors | 0603
5 | C15 | 1 | Murata Electronics | GRM188R61E106KA73D | 10.0µF ceramic capacitors | 0603
6 | D1 | 1 | Diodes Incorporated | 1N4004-T | DIODE | DO41-10
7 | R1, R2, R4 | 3 | Vishay / Dale | RCC06031K00FKEA | 1kΩ resistor | 0603
8 | L2 | 1 | Murata Electronics | LQW18AS33NJ0CD | Inductors | 0603
9 | C13 | 1 | Taiyo Yuden | LMK107BJ475MAHT | 4.7µF ceramic capacitors | 0603
10 | U2 | 1 | Microchip Technology / Atmel | ATMEGA328P-AU | Popular 328P in QFP | TQFP32-08
11 | LS1 | 1 | TDK | SD1209T5-A1 | Buzzer | BUZZER-12MM
12 | Y2 | 1 | Murata Electronics | CSTNE16M0V51Z000R0 | Resonators 16.0MHz 5pF 0.5% Cer Res Thk Exp mode | CSTNE16M0V51Z000R0
13 | DC1 | 1 | Gravitech | CON-SOCJ-2155 | DC Power Jack | DC-21MM
14 | JP1 | 1 | Harwin | M20-9770746 | PIN HEADER | 1X07
15 | U1 | 1 | FTDI | FT232RL-REEL | FT232RL USB UART | SSOP28DB
16 | C5, C8, C14 | 3 | Murata Electronics | GRM31CR61A107ME05L | Multilayer Ceramic Capacitors MLCC - SMD/SMT 100UF 10V 20% 1206 | CAPC3216X180N
17 | ICSP | 1 | Harwin | M20-9980346 | PIN HEADER | 2X03
18 | JP2 | 1 | Harwin | M20-9990246 | JUMPER | JP1
19 | IC1 | 1 | STMicroelectronics | L7805CV | VOLTAGE REGULATOR | 78XXS
20 | LCD | 1 | Harwin | M20-9770746 | PIN HEADER | 1X07
21 | AC2 | 1 | STMicroelectronics | LIS3DHTR | Accelerometer 3-Axis 2g/16g 1.8V LGA16 STMicroelectronics LIS3DHTR Accelerometer IC, 3-axis, I2C, SPI 1.71 3.6 V, 16-Pin LGA | LIS3DHTR
22 | IC2 | 1 | Texas Instruments | LM1117IMP-3.3/NOPB | LM1117IMP-3.3/NOPB, Low Dropout Voltage Regulator, 1.5A, 3.3 V +/-1%, 4-Pin SOT-223 | SOT230P700X180-4N
23 | PWR | 1 | VCC | LTH3MM12VFR4100 | LED | LED3MM
24 | S1 | 1 | Omron Electronics | B3F-1000 | OMRON SWITCH | B3F-10XX
25 | RXLED | 1 | VCC | LTH3MM12VFR4500 | LED | LED3MM
26 | TXLED | 1 | VCC | LTH3MM12VFR4500 | LED | LED3MM
27 | J4 | 1 | Amphenol FCI | 61729-0010BLF | USB Type B Connector | USB-B-PTH

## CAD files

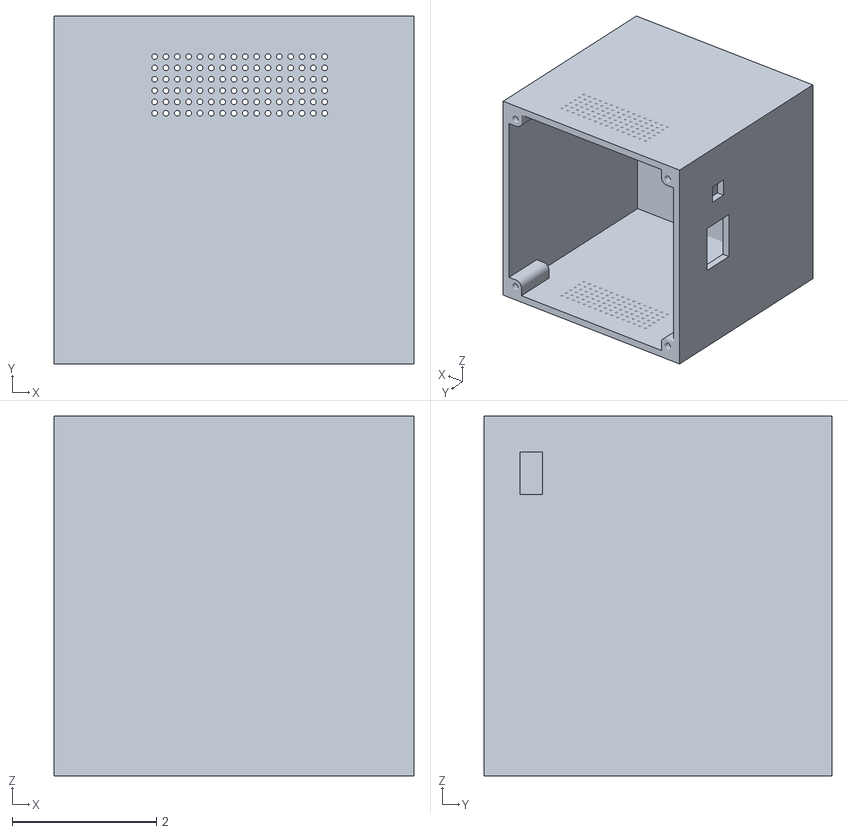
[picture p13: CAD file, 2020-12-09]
brd/HOLDER_3.1.stl
5.00 x 4.83 x 5.00

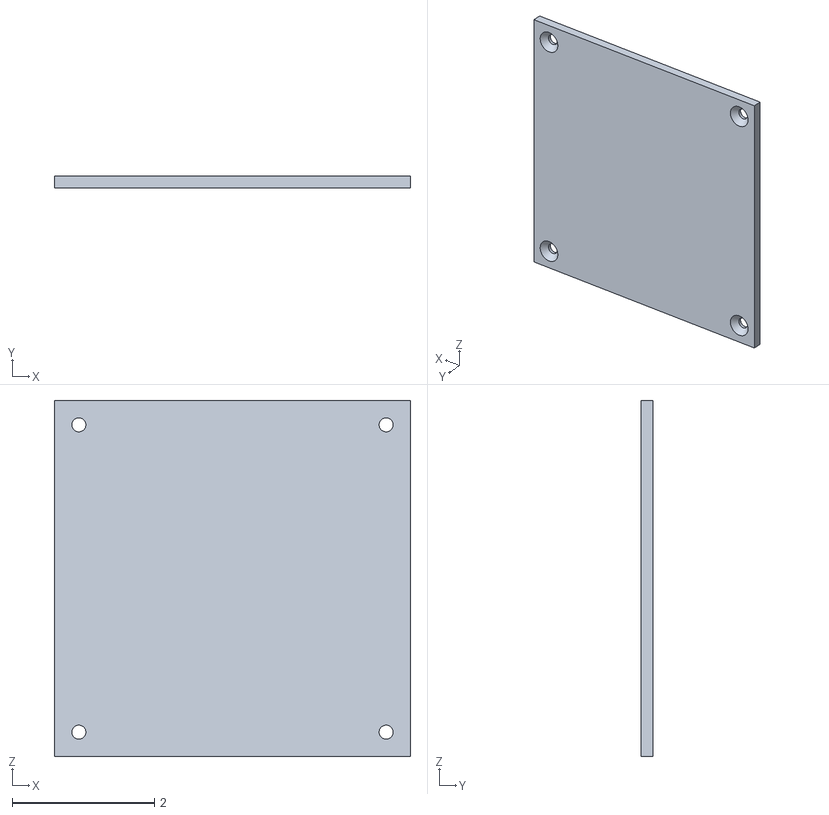
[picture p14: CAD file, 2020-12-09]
brd/LID_3.1.stl
5.00 x 0.167 x 5.00

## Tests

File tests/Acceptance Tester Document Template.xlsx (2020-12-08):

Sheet: Template
Test Writer:
Test Case Name: |  |  |  |  |  | Test ID:
Description: |  |  |  |  |  | Type: | □ white box □ black box
Tester Information
Name of Tester: |  |  |  |  |  | Data:
Hardware Version: |  |  |  |  |  | Time:
Setup:
Step | Action | Expected Result | Pass | Fail | N/A | Comments
1
2
3
Overall Test Result:

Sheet: Randomness Test
Test Writer: Jack Chen
Test Case Name: |  | All In One Dice Randomness Test |  |  |  | Test ID: | dice-RNG-6.1
Description: |  | Check that the random values generated are close to true random. Repetitive tests should also not consist of repeating patterns, signifying that the device is reseeding itself after each power cycle. |  |  |  | Type: | ☑ white box □ black box
Tester Information
Name of Tester: |  |  |  |  |  | Data:
Hardware Version: |  | Breadboard V2 |  |  |  | Time:
Setup: |  | The breadboard should consist of both the potentiometer and the accelerometer. One can either use production in `src/` for testing and read rolls off of the LCD display, or the supplied testbench in `tests/random/` and read values off of the terminal. Record all random values onto spreadsheet.
Step | Action | Expected Result | Pass | Fail | N/A | Comments
1 | Roll at least 30 random values between 1-100 | Very few repeated values in rolls (<5 times)
2 | Repeat step 1 5 times, powering down the system each repeat | Each reset has a different sequence of rolls
3 | Roll at least 20 random values between 1-20 | Few repeated values in rolls. Change range with potentiometer
4 | Roll at least 20 random values between 1-12 | Few repeated values in rolls. Change range with potentiometer
5 | Roll at least 20 random values between 1-10 | Few repeated values in rolls. Change range with potentiometer
6 | Roll at least 10 random values between 1-8 | Variation exists in rolls (not just same number)
7 | Roll at least 10 random values between 1-6 | Variation exists in rolls (not just same number)
7 | Roll at least 10 random values between 1-4 | Variation exists in rolls (not just same number)
Overall Test Result:

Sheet: LIS3DH Accelerometer Test
Test Writer: Jack Chen
Test Case Name: |  | LIS3DH Accelerometer Test |  |  |  | Test ID: | Acc-4.3
Description: |  | Check the accelerometer responds to a +- 2G force and determine the duration that the force needs to be sustained before a response is illicited. In production, a response is ellicited when shaken for at least 0.5s, but can this windows can be increased in code by increasing CLICKLATENCY for testing purposes. |  |  |  | Type: | □ white box ☑ black box
Tester Information
Name of Tester: |  |  |  |  |  | Data:
Hardware Version: |  | Breadboard V1.1 |  |  |  | Time:
Setup: |  | The LIS3DH accelerometer should be attached to the microcontroller via SPI interface. Terminal is set up to run at 9600 baud. Testing program should be located on `/tests/acceldemo`. A working accelerometer app should be installed on a phone. A stopwatch or clock may be on hand, but timing statements are also displayed on the terminal.
Step | Action | Expected Result | Pass | Fail | N/A | Comments
1 | Compile and upload test | Compiles and uploads successfully
2 | Estimate +- 2G acceleration via phone app | Distance and force exerted should be eyeballed by the tester using the phone app.
3 | Apply +- 2G force or more to accelerometer for 0.5s | The built-in LED should ellict a response and maintain being on for 2 seconds.
4 | Apply less than +- 2G force to accelerometer for 0.5s | The built-in LED should not ellicit a response
5 | Apply +- 2G force or more to accelerometer for less than 0.5s | The built-in LED should not ellicit a response.
6 | Constantly apply a +- 2G force for 0.5s + 2s | The built-in LED turns on and stays for 2s, then it should turn off and shortly back on.
Overall Test Result:

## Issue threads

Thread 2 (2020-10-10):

Make high-level algorithm for code

jackchen0226, 2020-10-10:
Could be a flowchart, or pseudocode. Ideally the algorithm is simple enough to explain to a 5 year old and streamline the programming process.

NFellows, 2020-10-14:
I made a high level flow chart to go along with some pseudo code I wrote. It's all super rough and I have some concerns about execution that we can go over in the meeting tonight 10/14 at 6:30 PM.

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
[411 High Level Code.docx](https://github.com/jackchen0226/all-in-one-die/files/5381361/411.High.Level.Code.docx)

DonutVendor, 2020-10-15:
Int maxRoll = 20;
Float roll_threshold = 5;

Void loop()
if (getTotalAcceleration() > roll_threshold)
rollDice();

if(digitalRead(increaseButton))
    increaseMaxRoll();

if(digitalRead(decreaseButton))
    decreaseMaxRoll();

Float getTotalAcceleration()
    Float x, y, z = 0;
    for(1:10)
        x+= getXAcceleration();
        y+= getXAcceleration();
        z+= getXAcceleration();

    x/= 10; y/= 10; z/= 10;

return sqrt(X*X + Y*Y + Z*Z);

Void rollDice()
    Int newRoll = Random.Range(0, maxroll);

    updateDisplay(newRoll);

Void updateDisplay(int num)
    //This function will depend on what type of display we have, and how we interface with it

Void increaseMaxRoll()
    maxRoll++;
    if(maxRoll > 20)
        maxRoll = 20;

Void decreaseMaxRoll()
    maxRoll--;
    if(maxRoll < 4)
        maxRoll = 4;

DonutVendor, 2020-10-15:
public enum Dice{
    4Sided,
    6Sided,
    8Sided,
    20Sided
}

jackchen0226, 2020-10-15:
We could use enums,

However it may be better to have a table +  max size of table for expandability and change the die index.

dies = [4, 6, 8, 10, 12, 20]
num_dies = 6
curr_die_index = 1; // d6

jackchen0226, 2020-10-15:
`
POWER ON
PROMPT USER FOR DIE VALUE
	WAIT FOR INPUT
		IF NO INPUT
GO BACK TO PROMPT
		IF INPUT
			WAIT FOR SHAKE FOR ~5s
				CHECK FOR DIE SIZE
				IF SHAKEN
					PULL RANDOM NUM
						CHECK IF D20 WAS ROLLED
							PLAY CURSE IF ROLLED A 1
					DISPLAY VALUE
					ROLL SAME DIE?
						GO BACK TO WAIT FOR SHAKE
						POWER OFF TO QUIT
				IF NOT SHAKEN
					GO BACK TO PROMPT FOR DIE VALUE
					POWER OFF TO QUIT
`
Nicole's pseudocode

Closed 2020-10-22.

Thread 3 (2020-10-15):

PCB Board Design

DonutVendor, 2020-10-15:

DonutVendor, 2020-10-15:
Start here: https://www.sparkfun.com/tutorials/108

DonutVendor, 2020-10-15:
Makes use of a FT232R Chip to serve as a USB to UART/RS232 serial covnerter.

https://www.ftdichip.com/Products/ICs/FT232R.htm

DonutVendor, 2020-10-15:
FT232R Connections:

TXD - connects to ATMega328P port PD1(TXD)
RXD - connects to ATMega328P port PD0(RXD)

CTS - Not needed (Clear To Send) Used in handshaking.
RTS - Not needed (Request To Send) Used in handshaking.
DTR - Connects to Auto Reset mechanism (connects through 100nF capacitor)
Auto-reset is a jumper that will enable auto-resetting of the chip upon uploading new code (RECOMMENDED)

TXLED - connects to RX LED
RXLED - connects to RX LED

DonutVendor, 2020-10-15:
ATMega328P does need to be on the riser, as the chip needs to be flashed...

Figure out how to flash the ATMega328P.

DonutVendor, 2020-10-20:
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
Board Schematic V1

DonutVendor, 2020-10-20:
Added Accelerometer to board. Currently configured in: Normal Mode, +-6g Full-scale, Normal Power Mode

DonutVendor, 2020-10-22:
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
Board Schematic V2

DonutVendor, 2020-10-30:
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
Board Schematic V3

- Cleaned things up
- USB Power disconnected from main power
- USB power only powers the FT232R chip
- Speaker plug in
- Accelerometer pins exposed for testing purposes

NFellows, 2020-12-05:
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
12/06/2020
Got parts soldered on. Some of the ceramic capacitors broke apart during assembly,  have backups on the way. The accelerometer will need to be attached off board because the actual ship can only be attached with heat.

Closed 2020-12-08.

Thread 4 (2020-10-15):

Bill of Materials

jackchen0226, 2020-10-15:

NFellows, 2020-10-15:
Possible Bill of Materials:

ATMega328P - https://www.microchip.com/wwwproducts/en/ATmega328p
OR
https://www.amazon.com/Fii-X3-Atmega328P-PU-Bundle-Sockets/dp/B018ZR3F7O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

Battery - https://www.adafruit.com/product/727

Possible Accelerator:
https://www.mouser.com/ProductDetail/Analog-Devices/ADXL327BCPZ?qs=WIvQP4zGanhwHjckzi5o%2Fg%3D%3D

Screen - https://www.amazon.com/UCTRONICS-SSD1306-Self-Luminous-Display-Raspberry/dp/B072Q2X2LL

DonutVendor, 2020-10-15:
Final Bill of Materials: (WIP)

Breadboard Prototyping:
- [ ] ATMega328P [[Amazon](https://www.amazon.com/Fii-X3-Atmega328P-PU-Bundle-Sockets/dp/B018ZR3F7O/), [Microchip](https://www.microchip.com/wwwproducts/en/ATmega328p)]
- [ ] Accelerometer [[Adafruit](https://www.adafruit.com/product/2809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)]
- [ ] LCD Screen [[Amazon](https://www.amazon.com/UCTRONICS-SSD1306-Self-Luminous-Display-Raspberry/dp/B072Q2X2LL)]
- [ ] Mini USB to Serial Converter [[Amazon](https://www.amazon.com/HiLetgo-FT232RL-Converter-Adapter-Breakout/dp/B00IJXZQ7C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)]

Final PCB: (Parts provided by PCBWay)
- [ ] ATMega328P (Processor)
- [ ] FT232RL (USB to Serial Converter Chip)

Final Construction:
- [ ] Assembled PCB
- [ ] LCD Screen [[Amazon](https://www.amazon.com/UCTRONICS-SSD1306-Self-Luminous-Display-Raspberry/dp/B072Q2X2LL)]
- [ ] 4xAA Battery Holder [[Amazon-Flat](https://www.amazon.com/LAMPVPATH-Battery-Holder-Leads-Wires/dp/B07T7MTRZX/), [Amazon-Fat](https://www.amazon.com/LAMPVPATH-Battery-Connector-Plastic-Housing/dp/B01MAXT00Q/)]

jackchen0226, 2020-10-22:
For power

The ATMega328P can run on 1.8V minimum, but can run at 3.3V or 4.5-5.5V. Batteries (AA-AAAA) give 1.5V each, but lithium cells are also an option (about 3V).

The LCD screen requires 3.3-5V.

Accelerometer also works on 3,3V

jackchen0226, 2020-11-14:
Added an initial Bill of Materials for the PCB design.

https://github.com/jackchen0226/all-in-one-die/wiki/Bill-of-Materials

Closed 2020-11-14.

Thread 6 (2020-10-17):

Casing Desing

micromort, 2020-10-17:
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
Super simple sketches. But I am a bit confused about some of the requirements. Can't the batteries and USB stuff be inside the casing? It should be handheld, and not needing to feed wires out of it. The casing will be in half and snap together (hopefully). Also for the screen/button(or dial) should they be full cut outs or how are we going to place them in? Please give feedback so new sketches/more in depth sketches can be made.

DonutVendor, 2020-10-20:
Rough Board Dimensions: 80mmx45mm. It could potentially get even smaller, but it shouldn't get any bigger than that. Also, I think the battery pack will be inside, like AAA's or something.

micromort, 2020-11-01:
[Bottom_Half_draft_v1.pdf](https://github.com/jackchen0226/all-in-one-die/files/5471772/Bottom_Half_draft_v1.pdf)

micromort, 2020-11-01:
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

micromort, 2020-11-01:
the pdf is the drawing with dimensions - super rough draft

micromort, 2020-11-01:
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

micromort, 2020-11-01:
Basic look into the bottom half grating for sound to come out of

micromort, 2020-11-01:
[Bottom Half Draft v2.pdf](https://github.com/jackchen0226/all-in-one-die/files/5471811/Bottom.Half.Draft.v2.pdf)

micromort, 2020-11-29:
[HOLDER_3.1.zip](https://github.com/jackchen0226/all-in-one-die/files/5613058/HOLDER_3.1.zip)

Closed 2020-11-29.

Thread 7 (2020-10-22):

Start coding an early breadboard prototype using Arduino Board

NFellows, 2020-10-22:

NFellows, 2020-10-22:
2020-10-18

Started testing the Adafruit LIS3DH with an Arduino Uno. The initial test showed that the accelerometer can be set to trigger a "click" when a certain threshold is passed when shaken. This "click" registers a HIGH on a pin on the Adafruit chip, this pin is currently being used to trigger an LED to adjust sensitivity.

NFellows, 2020-10-28:
Here is what I have set up on the breadboard prototype so far. I'm using an active buzzer for the "cuss response". Currently, I've been using the serial monitor to check responses with the plan to change the print statements to display on the oled screen. I've been using a 10k pot to select the values for the rolls. I'll be posting the rough testing code I've been working on so we can work out the kinks as a team.

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

NFellows, 2020-10-29:
I posted the code I've been working with for some testing. I need to update the sketches above because I took out the LED since it wasn't necessary for testing moving forward.

NFellows, 2020-10-29:
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

NFellows, 2020-11-07:
Working on getting the timing right with using the potentiometer to select dice values. I have it checking to see if the value stays the same after cycling through the loop so it knows to kick out, it's still a little buggy though. A person could certainly accidentally enter a wrong value by being either too fast/slow with the dial turns.

 I had to order more Oled screens because the single one I had stopped working. I'm not sure what happened since I haven't been using it for testing. I'm running example codes for the screen on the arduino to see what the problem is but I don't want to waste too much time on fixing a broken part when I should have the new ones in this weekend. I added in the functionality of displaying a sad tone when a 1 is rolled. I've got video of the buzzer in action but sadly can't post it here.

A big issue I'm having now is in the random number generator library I've been using for rolls, it's definitely not random enough so I'm hoping to bounce some ideas off the team to see what our best options are.

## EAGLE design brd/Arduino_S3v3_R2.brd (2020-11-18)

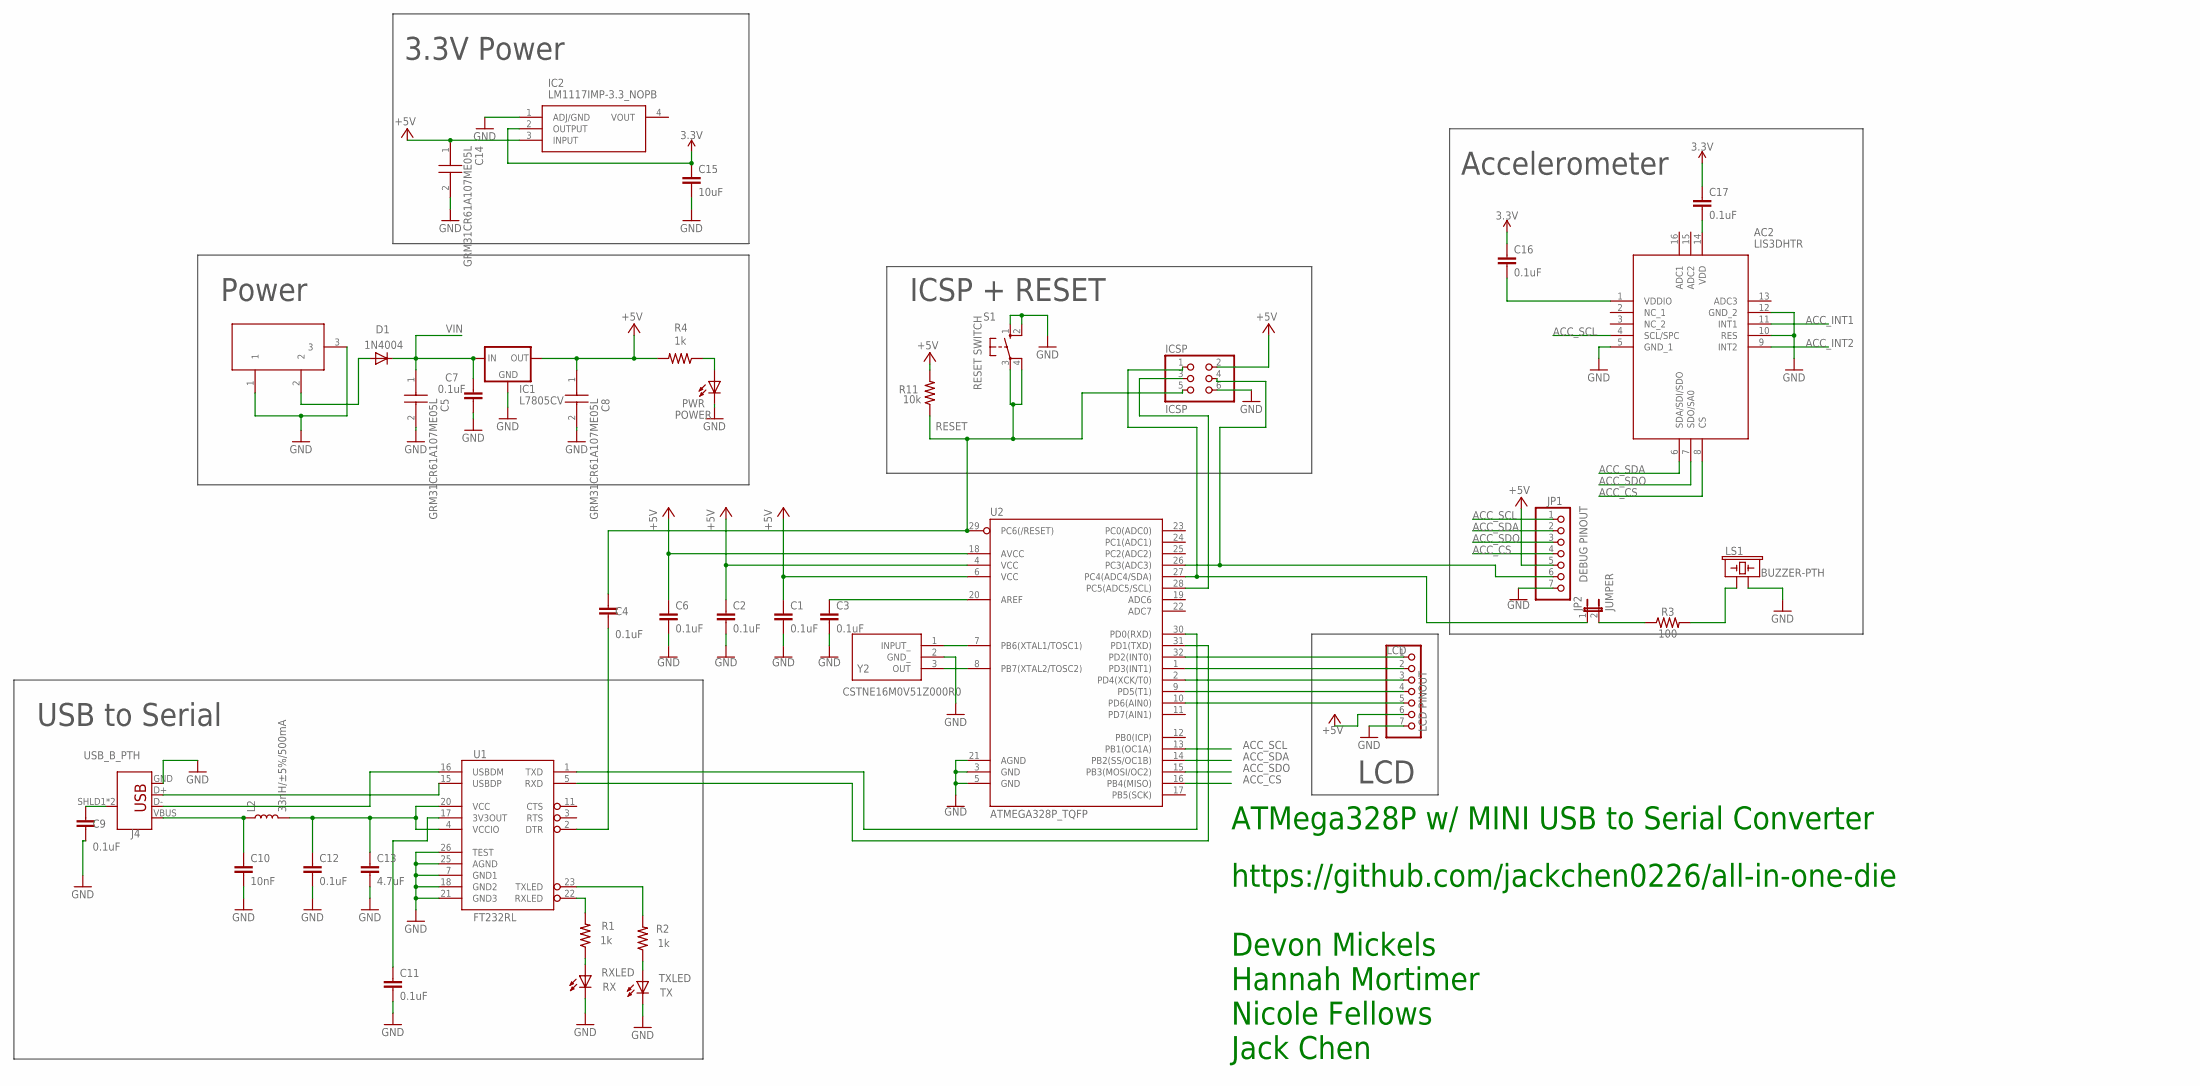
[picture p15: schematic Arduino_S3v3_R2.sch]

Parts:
AC2: LIS3DHTR
C1, C2, C3, C4, C6, C7, C9, C11, C12, C16, C17: 0.1uF; 0603; MPN C0603X104K5RAC3316
C5, C8, C14: GRM31CR61A107ME05L; CAPC3216X180N
C10: 10nF; 0603; MPN C0603C103K5RAC7013
C13: 4.7uF; 0603; MPN LMK107BJ475MAHT
C15: 10uF; 0603; MPN GRM188R61E106KA73D
D1: 1N4004; DO41-10; MPN 1N4004-T
DC1: DC21MMX; DC-21MM; MPN CON-SOCJ-2155
IC1: L7805CV; 78XXS; MPN L7805CV
IC2: LM1117IMP-3.3_NOPB; SOT230P700X180-4N
ICSP: ICSP; 2X03; MPN M20-9980346
J4: USB_B_PTH; USB-B-PTH; MPN 61729-0010BLF
JP1: DEBUG PINOUT; 1X07; MPN M20-9770746
JP2: JUMPER; JP1; MPN M20-9990246
L2: 33nH/±5%/500mA; 0603; MPN LQW18AS33NJ0CD
LCD: LCD PINOUT; 1X07; MPN M20-9770746
LS1: BUZZER-PTH; BUZZER-12MM; MPN SD1209T5-A1
PWR: POWER; LED3MM; MPN LTH3MM12VFR4100
R1, R2, R4: 1k; 0603; MPN RCC06031K00FKEA
R3: 100; 0603; MPN RCC0603100RFKEA
R11: 10k; 0603; MPN ERJ-UP3D1002V
RXLED: RX; LED3MM; MPN LTH3MM12VFR4500
S1: RESET SWITCH; B3F-10XX; MPN B3F-1000
TXLED: TX; LED3MM; MPN LTH3MM12VFR4500
U1: FT232RL; SSOP28DB; MPN FT232RL-REEL
U2: ATMEGA328P_TQFP; TQFP32-08; MPN ATMEGA328P-AU
Y2: CSTNE16M0V51Z000R0

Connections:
3.3V: C15.1, C16.1, C17.1, IC2.2 (OUTPUT)
+5V: C1.1, C2.1, C6.1, C8.1, C14.1, IC1.OUT, IC2.3 (INPUT), ICSP.2, JP1.5, LCD.6, R4.2, R11.2, U2.4 (VCC), U2.6 (VCC), U2.18 (AVCC)
ACC_CS: AC2.8 (CS), JP1.4, U2.16 (PB4(MISO))
ACC_INT1: AC2.11 (INT1)
ACC_INT2: AC2.9 (INT2)
ACC_SCL: AC2.4 (SCL/SPC), JP1.1, U2.13 (PB1(OC1A))
ACC_SDA: AC2.6 (SDA/SDI/SDO), JP1.2, U2.14 (PB2(SS/OC1B))
ACC_SDO: AC2.7 (SDO/SA0), JP1.3, U2.15 (PB3(MOSI/OC2))
BUZZ: ICSP.1, JP2.1, U2.27 (PC4(ADC4/SDA))
GND: AC2.5 (GND_1), AC2.10 (RES), AC2.12 (GND_2), C1.2, C2.2, C3.2, C5.2, C6.2, C7.1, C8.2, C9.2, C10.2, C11.2, C12.2, C13.2, C14.2, C15.2, DC1.1, DC1.3, IC1.GND, IC2.1 (ADJ/GND), ICSP.6, J4.GND, JP1.7, LCD.7, LS1.- (2), PWR.K (C), RXLED.K (C), S1.1 (S), S1.2 (S1), TXLED.K (C), U1.7 (GND1), U1.18 (GND2), U1.21 (GND3), U1.25 (AGND), U1.26 (TEST), U2.3 (GND), U2.5 (GND), U2.21 (AGND), Y2.2 (GND_)
LCD_CS: LCD.1, U2.32 (PD2(INT0))
LCD_SCL: LCD.4, U2.9 (PD5(T1))
LCD_SDA: LCD.3, U2.2 (PD4(XCK/T0))
LCD_SDO: LCD.2, U2.1 (PD3(INT1))
unnamed: U2.7 (PB6(XTAL1/TOSC1)), Y2.1 (INPUT_)
unnamed: C9.1, J4.SHLD1 (SHIELD), J4.SHLD2 (SHIELD)
unnamed: PWR.A, R4.1
unnamed: C4.2, U1.2 (DTR)
unnamed: AC2.14 (VDD), C17.2
unnamed: U2.8 (PB7(XTAL2/TOSC2)), Y2.3 (OUT)
unnamed: AC2.1 (VDDIO), C16.2
unnamed: D1.A, DC1.2
unnamed: J4.D+, U1.15 (USBDP)
unnamed: LCD.5, U2.10 (PD6(AIN0))
unnamed: JP2.2, R3.1
unnamed: LS1.+ (1), R3.2
unnamed: ICSP.3, U2.28 (PC5(ADC5/SCL))
unnamed: C3.1, U2.20 (AREF)
unnamed: C11.1, U1.17 (3V3OUT)
unnamed: J4.D-, U1.16 (USBDM)
unnamed: C10.1, J4.VBUS, L2.1
unnamed: R2.1, TXLED.A
unnamed: R1.1, RXLED.A
POTIN: ICSP.4, JP1.6, U2.26 (PC3(ADC3))
RESET: C4.1, ICSP.5, R11.1, S1.3, S1.4 (P1), U2.29 (PC6(/RESET))
RXD: U1.5 (RXD), U2.31 (PD1(TXD))
RXLED: R1.2, U1.22 (RXLED)
TXD: U1.1 (TXD), U2.30 (PD0(RXD))
TXLED: R2.2, U1.23 (TXLED)
VBUS: C12.1, C13.1, L2.2, U1.4 (VCCIO), U1.20 (VCC)
VIN: C5.1, C7.2, D1.C, IC1.IN

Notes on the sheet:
https://github.com/jackchen0226/all-in-one-die Devon Mickels Hannah Mortimer Nicole Fellows Jack Chen
ATMega328P w/ MINI USB to Serial Converter
Power
USB to Serial
ICSP + RESET
Accelerometer
LCD
3.3V Power

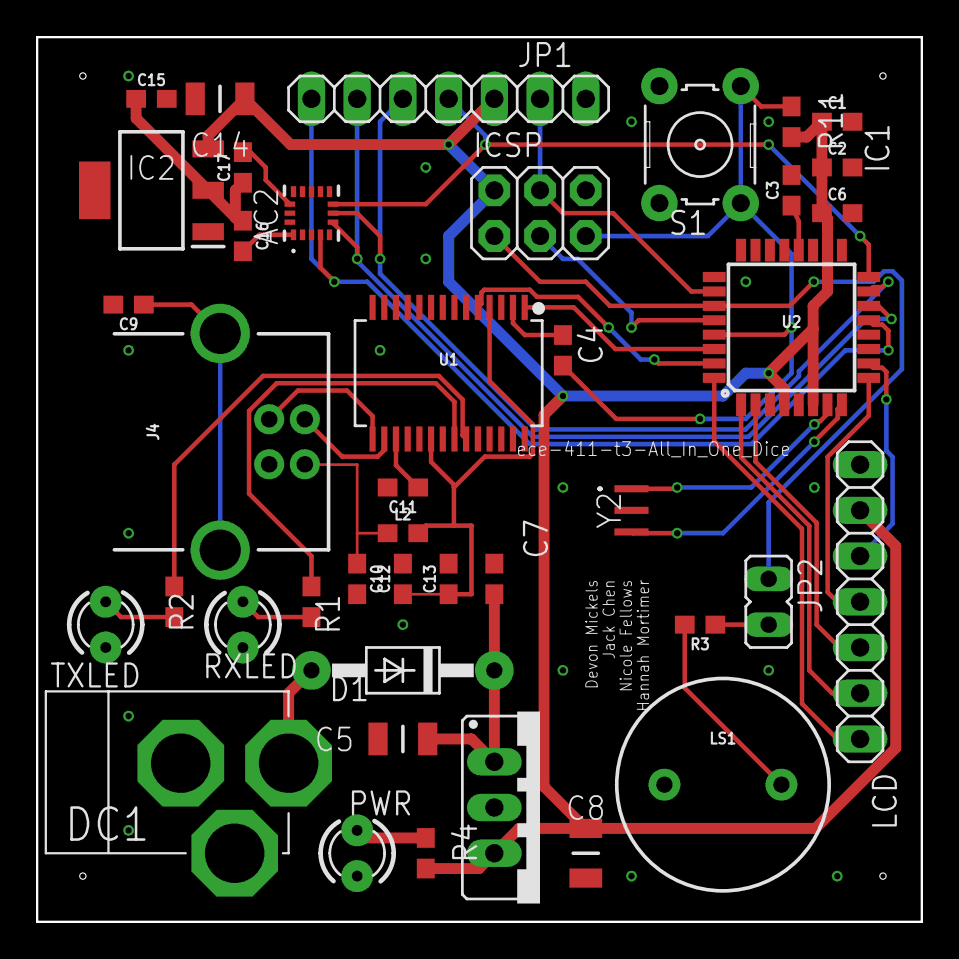
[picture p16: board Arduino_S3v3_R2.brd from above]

Board: 2 copper layers, 49.1 x 49.1 mm, 41 parts (0 on the bottom side), 39 nets.

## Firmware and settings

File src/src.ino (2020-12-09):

#include <Wire.h>
#include <SPI.h>
#include <Adafruit_LIS3DH.h>
#include <Adafruit_Sensor.h>
#include <Adafruit_GFX.h>
#include <Adafruit_SSD1306.h>

// _______________DISPLAY________________
#define SCREEN_WIDTH 128  // OLED display width, in pixels
#define SCREEN_HEIGHT 32  // OLED display height, in pixels

#define CHAR_HEIGHT 8     // Height of character in standard font
#define CHAR_WIDTH  6     // Width of the character in standard font

// J.C: We have 2 types of display connections, comment out the one you're NOT using
// I2C connected SSD1306 display
#define OLED_RESET    -1 // Reset pin # (or -1 if sharing Arduino reset pin)
#define OLED_ADDR 0x3C   // Address of the OLED display
// With the Wire library, the I2C pins of the board you're programming for
// is set to a default. For ESP32 it is the SCL and SDA pins
// for the uno/atmega it is ADC 5 (SCL) and ADC 4 (SDA) - J.C
Adafruit_SSD1306 display(SCREEN_WIDTH, SCREEN_HEIGHT, &Wire, OLED_RESET);

/*
// SPI connected SSD1306 display
#define OLED_MOSI   9	// Master output, Slave input (D1 on chip)
#define OLED_CLK   10	// Clock (D0 on chip)
#define OLED_DC    11	// Data/Command pin (DC on chip)
#define OLED_CS    12	// Chip select (CS on chip)
#define OLED_RESET 13	// Reset (RST on chip)
Adafruit_SSD1306 display(SCREEN_WIDTH, SCREEN_HEIGHT,
  OLED_MOSI, OLED_CLK, OLED_DC, OLED_RESET, OLED_CS);
*/


// ________________ACCELEROMETER________________
// Used for software SPI
#define LIS3DH_CLK 	13	// Clock (SCK on chip)
#define LIS3DH_MISO 12	// Master input, Slave output (SDO on chip)
#define LIS3DH_MOSI 11	// Master output, Slave input (SDA on chip)
// Used for hardware & software SPI
#define LIS3DH_CS 	10	// Chip select (CS on chip)
//#define LIS3DH_INT	21	// Interrupt pin (INT on chip), disable if not in use -J.C
Adafruit_LIS3DH lis = Adafruit_LIS3DH(LIS3DH_CS, LIS3DH_MOSI, LIS3DH_MISO, LIS3DH_CLK);

// Adjust this number for the sensitivity of the 'click' force
// this strongly depend on the range! for 16G, try 5-10
// for 8G, try 10-20. for 4G try 20-40. for 2G try 40-80
#define CLICKTHRESHHOLD 125

// These values are only used if LIS3DH_INT is used for rolling animation 
// ODR is defined with lis.setDataRate() in setup() -J.C
#define CLICKLIMIT	13	// Time in 1/ODR that acceleration must be maintained for a click
#define CLICKLATENCY 50	// Time in 1/ODR that the interrupt remains high 


// ____________POTENTIOMETER_____________
// DEFINITIONS FOR POTENTIOMETER
#define ROLLd4 4
#define ROLLd6 6
#define ROLLd8 8
#define ROLLd10 10
#define ROLLd12 12
#define ROLLd20 20

const int SENSOR_PIN = A0;  //sensor for pot
int sensorValue = 0;
#define ADC_MAX 1024        // maximum analog read value from ADC, 2048 for ESP32, 1024 for Uno/Atmega


// _____________BUZZER_________________
#define BUZZER_PIN 9	// Digital pin for buzzer control
// Used for the esp32 implementation of the buzzer, since tone() does not work -J.C
#define BUZZER_FREQ 2000  // PWM freq
#define BUZZER_CH 0       // Digital channel of the buzzer
#define RES 8             // Resolution


// ______________MISC_________________
int ROLL = 0;
#define USE_ESP32 false    // CHANGE IF BOARD IS ESP32 -J.C



void setup(void) {
  Serial.begin(9600);
  #ifndef ESP8266
    while (!Serial) yield();     // will pause Zero, Leonardo, etc until serial console opens
  #endif
  
  // ___________DISPLAY___________
  // Set up display at I2C address OLED_ADDR
	display.begin(SSD1306_SWITCHCAPVCC, OLED_ADDR);
	display.clearDisplay();
	display.display();


  // ___________ACCELEROMETER__________
	if (! lis.begin(0x18)) {   // change this to 0x19 for alternative i2c address
		Serial.println("Couldnt start");
	while (1) yield();
	}
	Serial.println("LIS3DH found!");

	lis.setRange(LIS3DH_RANGE_2_G);   // 2, 4, 8 or 16 G!

	Serial.print("Range = "); Serial.print(2 << lis.getRange());  
	Serial.println("G");
	// 0 = turn off click detection & interrupt
	// 1 = single click only interrupt output
	// 2 = double click only interrupt output, detect single click
	// Adjust threshhold, higher numbers are less sensitive
	//lis.setClick(1, CLICKTHRESHHOLD);

  // Alternative click using interrupt pins
  // Manually setting data rate of 25 Hz (40 ms, less than a fast reaction of 120 ms)
  lis.setDataRate(LIS3DH_DATARATE_25_HZ);
  lis.setClick(1, CLICKTHRESHHOLD, CLICKLIMIT, CLICKLATENCY);
	delay(100); 

  // ____________BUZZER___________
  if (USE_ESP32) {
    /*
    // Set up led PWM to be used for a buzzer
	  ledcSetup(BUZZER_CH, BUZZER_FREQ, RES);
    // Attach digital channel to physical pin
    ledcAttachPin(BUZZER_PIN, BUZZER_CH);
    ledcWrite(BUZZER_CH, 125);  // Set to 50% duty cycle (half of 2^RES)
    ledcWriteTone(BUZZER_CH, LOW);
    */
  }
  else {
    pinMode(BUZZER_PIN, OUTPUT);
  }
  
  //____________POTENTIOMETER AND RANDOMNESS___________
  // Randomness would be a generated value 
  // We use 3 sources of real-world randomness
  // 1) The fluctuations of an analog pin
  // 2) The x position of the accelerometer
  // 3) The y acceleration of the accelerometer
  //
  // We use x pos because testing had a fluctuation range of ~150
  // y acceleration chosen arbitrarily
  // analog pin to add another source of randomness
  // -J.C

  int pot_value = analogRead(SENSOR_PIN);
  lis.read();   // Gets X Y and Z data at once

  // Get the normalized acceleration event
  sensors_event_t event;
  lis.getEvent(&event);

  // Seed RNG
  // lis.x and event.acceleration.y can go negative, causing overflows
  // making this function more chaotic. Good for randomness -J.C.
  randomSeed((unsigned int)(lis.x * event.acceleration.y - pot_value));

}


void write_out(int curr_state, bool shaking, int roll) {
  // boilerplate, clear out display and set text
  display.clearDisplay();
  display.setTextSize(1);   // Font size to 2, characters are 12x16 pixels
  display.setTextColor(SSD1306_WHITE);  // Doesn't matter for most displays, can have 2 args for bg
  display.cp437(true);      // Set font as 'Code Page 437'

  display.setCursor(0, 0);

  // Display out current state
  // While currently each case has few differences, the following
  // should be kept in switch() statement for future implementation -J.C
  switch(curr_state) {
    case 1:
      display.println(F("CURRENT DICE:  D 1"));
      break;
    case ROLLd4:
      display.println(F("CURRENT DICE:  D 4"));
      break;
    case ROLLd6:
      display.println(F("CURRENT DICE:  D 6"));
      break;
    case ROLLd8:
      display.println(F("CURRENT DICE:  D 8"));
      break;
    case ROLLd10:
      display.println(F("CURRENT DICE:  D10"));
      break;
    case ROLLd12:
      display.println(F("CURRENT DICE:  D12"));
      break;
    case ROLLd20:
      display.println(F("CURRENT DICE:  D20"));
      break;
    default:
      display.write("CURRENT DICE: ");
      if (roll >= 100)
        display.write('D');
      else
        display.write(" D");
      display.write(curr_state / 100 + '0');        // Get 100s digital
      display.write((curr_state / 10) % 10  + '0'); // Get 10s digit (e.g. 323 / 10 == 32. 32 % 10 == 2
      display.write((curr_state % 10) + '0');
  }

  // Display if currently shaking
  if (shaking) {
    display.setTextSize(2);

    
    // Write to row 1
    display.setCursor(0, CHAR_HEIGHT*1);
    display.println(F("SHAKING!!!"));             // Size 2 font has 10 char max

    display.setTextSize(1);
    // Write to row 3
    display.setCursor(0, CHAR_HEIGHT*3);
    display.println(F(" ROLLING!  ROLLING! "));    // Size 1 font has 21 char max
 
    // Display the buffer, then begin scrolling display
    display.display();
    display.startscrollright(0x01, 0x0F);

    // Premature return to prevent double display, just in case.
    return;
  }
  else if (roll >= 0) {
    // Make sure to stop scrolling once roll is resolved
    display.stopscroll();

    display.setTextSize(2);
    display.setCursor(0, CHAR_HEIGHT*1);    // 5px offset centers 9, 2x chars
    display.write("ROLLED: ");

    /*
    if (roll > 99)
      display.setCursor(5, CHAR_HEIGHT*3);    // 5px offset centers 3, 3x chars
    else
      display.setCursor(14, CHAR_HEIGHT*3);   // 14 ps offset centers 2, 3X chars
    */
    if (roll >= 100)
      display.write(roll / 100 + '0');      // Get 100s digit
    // No support for rolls past 1000, need for expandability? -J.C.
    if (roll >= 10)
      display.write((roll / 10) % 10  + '0'); // Get 10s digit (e.g. 323 / 10 == 32. 32 % 10 == 2
    display.write((roll % 10) + '0');
  }
  else {
    display.setTextSize(1);
    display.setCursor(0, CHAR_HEIGHT*2);

    display.println(F("Shake die for 0.5s"));
  }

  display.display();

}


// Comment out if using ESP32 -J.C

void play_sound() {
    // Megalovania
    // Composed by Toby Fox
    // D3 eigth note (beamed)
    tone(BUZZER_PIN, 147);
    delay(63);
    noTone(BUZZER_PIN);
    delay(63);
    
    // D3 eigth note (beamed)
    tone(BUZZER_PIN, 147);
    delay(63);
    noTone(BUZZER_PIN);
    delay(63);
  
    // D4 eigth note, dotted rest (beamed)
    tone(BUZZER_PIN, 294);
    delay(125);
    noTone(BUZZER_PIN);
    delay(125);
  
    // A4 quarter note, dotted rest/end
    tone(BUZZER_PIN, 220);
    delay(250);
    noTone(BUZZER_PIN);
}
/*
void play_sound_esp32() {
  // Megalovania
  // Composed by Toby Fox
  // D3 eighth note (beamed)
  ledcWriteTone(BUZZER_CH, 147);
  delay(63);
  ledcWriteTone(BUZZER_CH, LOW);
  delay(63);

  // D3 eighth note (beamed)
  ledcWriteTone(BUZZER_CH, 147);
  delay(63);
  ledcWriteTone(BUZZER_CH, LOW);
  delay(63);

  // D4 eigth note, dotted rest (beamed)
  ledcWriteTone(BUZZER_CH, 294);
  delay(125);
  ledcWriteTone(BUZZER_CH, LOW);
  delay(125);

  // A4 quarter note, dotted rest/end
  ledcWriteTone(BUZZER_CH, 220);
  delay(250);
  ledcWriteTone(BUZZER_CH, LOW);
}
*/
// Variables deprecated -J.C
int diceNum;
int passRoll;
int check;
int flag = 1;

bool curr_shaking, prev_shaking;
bool display_shake;
int curr_dice_state;
void loop() {
  // Get and map a value from potentiometer
  // Currently it is just a linearly 6 binned map, can be adjusted -J.C.
  // 0 -> d4
  // 1 -> d6
  // 2 -> d8
  // 3 -> d10
  // 4 -> d12
  // 5 -> d20
  sensorValue = analogRead(SENSOR_PIN);
  sensorValue = map(sensorValue, 0, ADC_MAX, 0, 8);

  switch (sensorValue) {
    case 0:
      curr_dice_state = 1;
      break;
    case 1:
      curr_dice_state = ROLLd4;
      break;
    case 2:
      curr_dice_state = ROLLd6;
      break;
    case 3:
      curr_dice_state = ROLLd8;
      break;
    case 4:
      curr_dice_state = ROLLd10;
      break;
    case 5:
      curr_dice_state = ROLLd12;
      break;
    case 6:
      curr_dice_state = ROLLd20;
      break;
    default:
      curr_dice_state = 100;
      break;
  }

  // Get interrupt from accelerometer
  uint8_t click = 0;
  click = lis.getClick();

  // Boilerplate
  if (!(click & 0x30)) {
    curr_shaking = false;
    // No roll occurred, check if we shook last check
    
    if (prev_shaking) {
      // When we have a previous shake, but not current shake
      // signifies we've finished shake and ready to show roll
      // click transitioned from 1 -> 0
      ROLL = random(1, curr_dice_state);
      display_shake = false;

    }
    else {
      // If not, then we have not rolled anything
      // Display out that we're not shaking
      ROLL = -1;
      display_shake = false;
    }

  }
  else if (click & 0x10) {
    curr_shaking = true;
    // Roll occurred, check if we shook the last check
    if (prev_shaking) {
      // previously was shaking, so keep shaking
      ROLL = -1;
      display_shake = true;
    }
    else {
      // previous not shaking, so this must be the first shaking
      ROLL = -1;
      display_shake = true;
    }
  }

  write_out(curr_dice_state, display_shake, ROLL);
  // If we did display out the roll, we should wait and let it linger for a few
  // Roll only ever displayed when we previously shook and current not shaking
  if (prev_shaking & !curr_shaking) {
    if (ROLL == 1)
      //play_sound_esp32();
      play_sound();
    delay(5000);
  }

  // Add short delay.
  // Ideally this would be a sleep to reduce power consumption -J.C.
  delay(200);
  // At the end of loop, make curr_shaking to prev_shaking
  prev_shaking = curr_shaking;
}

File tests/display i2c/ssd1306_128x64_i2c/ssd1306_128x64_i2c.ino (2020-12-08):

/**************************************************************************
 This is an example for our Monochrome OLEDs based on SSD1306 drivers

 Pick one up today in the adafruit shop!
 ------> http://www.adafruit.com/category/63_98

 This example is for a 128x64 pixel display using I2C to communicate
 3 pins are required to interface (two I2C and one reset).

 Adafruit invests time and resources providing this open
 source code, please support Adafruit and open-source
 hardware by purchasing products from Adafruit!

 Written by Limor Fried/Ladyada for Adafruit Industries,
 with contributions from the open source community.
 BSD license, check license.txt for more information
 All text above, and the splash screen below must be
 included in any redistribution.
 **************************************************************************/

#include <SPI.h>
#include <Wire.h>
#include <Adafruit_GFX.h>
#include <Adafruit_SSD1306.h>

#define SCREEN_WIDTH 128 // OLED display width, in pixels
#define SCREEN_HEIGHT 64 // OLED display height, in pixels

// Declaration for an SSD1306 display connected to I2C (SDA, SCL pins)
#define OLED_RESET     -1 // Reset pin # (or -1 if sharing Arduino reset pin)
Adafruit_SSD1306 display(SCREEN_WIDTH, SCREEN_HEIGHT, &Wire, OLED_RESET);

#define NUMFLAKES     10 // Number of snowflakes in the animation example

#define LOGO_HEIGHT   16
#define LOGO_WIDTH    16
static const unsigned char PROGMEM logo_bmp[] =
{ B00000000, B11000000,
  B00000001, B11000000,
  B00000001, B11000000,
  B00000011, B11100000,
  B11110011, B11100000,
  B11111110, B11111000,
  B01111110, B11111111,
  B00110011, B10011111,
  B00011111, B11111100,
  B00001101, B01110000,
  B00011011, B10100000,
  B00111111, B11100000,
  B00111111, B11110000,
  B01111100, B11110000,
  B01110000, B01110000,
  B00000000, B00110000 };

void setup() {
  Serial.begin(9600);

  // SSD1306_SWITCHCAPVCC = generate display voltage from 3.3V internally
  if(!display.begin(SSD1306_SWITCHCAPVCC, 0x3C)) { // Address 0x3C for 128x64
    Serial.println(F("SSD1306 allocation failed"));
    for(;;); // Don't proceed, loop forever
  }

  // Show initial display buffer contents on the screen --
  // the library initializes this with an Adafruit splash screen.
  display.display();
  delay(2000); // Pause for 2 seconds

  // Clear the buffer
  display.clearDisplay();

  // Draw a single pixel in white
  display.drawPixel(10, 10, SSD1306_WHITE);

  // Show the display buffer on the screen. You MUST call display() after
  // drawing commands to make them visible on screen!
  display.display();
  delay(2000);
  // display.display() is NOT necessary after every single drawing command,
  // unless that's what you want...rather, you can batch up a bunch of
  // drawing operations and then update the screen all at once by calling
  // display.display(). These examples demonstrate both approaches...

  /*
  testdrawline();      // Draw many lines

  testdrawrect();      // Draw rectangles (outlines)

  testfillrect();      // Draw rectangles (filled)

  testdrawcircle();    // Draw circles (outlines)

  testfillcircle();    // Draw circles (filled)

  testdrawroundrect(); // Draw rounded rectangles (outlines)

  testfillroundrect(); // Draw rounded rectangles (filled)

  testdrawtriangle();  // Draw triangles (outlines)

  testfilltriangle();  // Draw triangles (filled)

  testdrawchar();      // Draw characters of the default font

  testdrawstyles();    // Draw 'stylized' characters

  testscrolltext();    // Draw scrolling text

  testdrawbitmap();    // Draw a small bitmap image
  
  // Invert and restore display, pausing in-between
  display.invertDisplay(true);
  delay(1000);
  display.invertDisplay(false);
  delay(1000);

  testanimate(logo_bmp, LOGO_WIDTH, LOGO_HEIGHT); // Animate bitmaps
  */

  
}

void loop() {

  display.clearDisplay();

  testscrolltext();
  display.clearDisplay();
  display.setTextSize(2);     // 1:1 pixel scale
  display.setTextColor(SSD1306_WHITE);
  display.setCursor(0, 0);
  display.cp437(true);      // Code Page 427 font, 256 chars

  display.write("Shake die for 0.5s  to roll ");
  display.display();
  delay(5000);

  
  
  //testdrawchar();
}

void testdrawline() {
  int16_t i;

  display.clearDisplay(); // Clear display buffer

  for(i=0; i<display.width(); i+=4) {
    display.drawLine(0, 0, i, display.height()-1, SSD1306_WHITE);
    display.display(); // Update screen with each newly-drawn line
    delay(1);
  }
  for(i=0; i<display.height(); i+=4) {
    display.drawLine(0, 0, display.width()-1, i, SSD1306_WHITE);
    display.display();
    delay(1);
  }
  delay(250);

  display.clearDisplay();

  for(i=0; i<display.width(); i+=4) {
    display.drawLine(0, display.height()-1, i, 0, SSD1306_WHITE);
    display.display();
    delay(1);
  }
  for(i=display.height()-1; i>=0; i-=4) {
    display.drawLine(0, display.height()-1, display.width()-1, i, SSD1306_WHITE);
    display.display();
    delay(1);
  }
  delay(250);

  display.clearDisplay();

  for(i=display.width()-1; i>=0; i-=4) {
    display.drawLine(display.width()-1, display.height()-1, i, 0, SSD1306_WHITE);
    display.display();
    delay(1);
  }
  for(i=display.height()-1; i>=0; i-=4) {
    display.drawLine(display.width()-1, display.height()-1, 0, i, SSD1306_WHITE);
    display.display();
    delay(1);
  }
  delay(250);

  display.clearDisplay();

  for(i=0; i<display.height(); i+=4) {
    display.drawLine(display.width()-1, 0, 0, i, SSD1306_WHITE);
    display.display();
    delay(1);
  }
  for(i=0; i<display.width(); i+=4) {
    display.drawLine(display.width()-1, 0, i, display.height()-1, SSD1306_WHITE);
    display.display();
    delay(1);
  }

  delay(2000); // Pause for 2 seconds
}

void testdrawrect(void) {
  display.clearDisplay();

  for(int16_t i=0; i<display.height()/2; i+=2) {
    display.drawRect(i, i, display.width()-2*i, display.height()-2*i, SSD1306_WHITE);
    display.display(); // Update screen with each newly-drawn rectangle
    delay(1);
  }

  delay(2000);
}

void testfillrect(void) {
  display.clearDisplay();

  for(int16_t i=0; i<display.height()/2; i+=3) {
    // The INVERSE color is used so rectangles alternate white/black
    display.fillRect(i, i, display.width()-i*2, display.height()-i*2, SSD1306_INVERSE);
    display.display(); // Update screen with each newly-drawn rectangle
    delay(1);
  }

  delay(2000);
}

void testdrawcircle(void) {
  display.clearDisplay();

  for(int16_t i=0; i<max(display.width(),display.height())/2; i+=2) {
    display.drawCircle(display.width()/2, display.height()/2, i, SSD1306_WHITE);
    display.display();
    delay(1);
  }

  delay(2000);
}
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

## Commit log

2020-11-05 Added EagleCAD files.
    [Arduino_S3v3_R2.brd, Arduino_S3v3_R2.sch]
2020-11-10 Added buzzer, adjusted for SPI, new accel, pot in
    [Arduino_S3v3_R2.brd, Arduino_S3v3_R2.sch]
2020-11-10 Board design final dimensions. Rough Draft ready.
    [Arduino_S3v3_R2.brd, Arduino_S3v3_R2.sch]
2020-11-12 Thickened lines for board outline to width 5
    [Arduino_S3v3_R2.brd, Arduino_S3v3_R2.sch]
2020-11-12 Added initial manufacturing part numbers
    [Arduino_S3v3_R2.brd, Arduino_S3v3_R2.sch]
2020-11-12 updated to SPI, replaced TH comps, new accel
    New accelerometer is not hooked up yet.
    [Arduino_S3v3_R2.brd, Arduino_S3v3_R2.sch]
2020-11-14 new accel, 3.3v regulator, final draft
    Ready for Board Review.
    [Arduino_S3v3_R2.brd, Arduino_S3v3_R2.sch]
2020-11-15 Modified according to Desgin Review w/ Greenberg
    [Arduino_S3v3_R2.brd, Arduino_S3v3_R2.sch]
2020-11-16 Modified after meeting w/ Team 13
    [Arduino_S3v3_R2.brd, Arduino_S3v3_R2.sch]
2020-11-18 Added BOM files
    [Arduino_S3v3_R2 (2).xlsx, Arduino_S3v3_R2.csv]
2020-11-18 Updated schematic with MPNS, MFRs for pin headers and others
    [Arduino_S3v3_R2.brd, Arduino_S3v3_R2.sch]
2020-11-18 Update .replit
    Current version of code 11/18/2020
2020-11-18 Moved board name to center of the board
    [Arduino_S3v3_R2.brd]
2020-12-07 Added implementation for an ESP32
2020-12-08 Added images of the latest version of board layer + schematic
2020-12-08 Added extensive test case documents + template
    [Acceptance Tester Document Template.xlsx]
2020-12-09 Added new buzzer test, fixed typo in accelerometer test
    [acceldemo.ino, buzzer.ino]
2020-12-09 Added define for maximum value of ADC
2020-12-09 Added extra comments for ESP32 and Uno/atmega differences
2020-12-09 Fixed binning of pot on ADC, changed defines for Uno/atmega
    [src.ino]
2020-12-09 Add files via upload
    STL files for the holder.
    [HOLDER_3.1.stl, LID_3.1.stl]

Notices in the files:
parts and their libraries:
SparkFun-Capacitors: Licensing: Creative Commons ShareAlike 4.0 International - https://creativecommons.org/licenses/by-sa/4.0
